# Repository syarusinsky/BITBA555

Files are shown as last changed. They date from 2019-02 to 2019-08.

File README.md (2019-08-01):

# BITBA555
BITBA555 is an open source/open hardware hybrid analog/digital monophonic synthesizer with a digital oscillator section and analog filter, amplifier, and envelope generator sections. It also features a fully 3D printable enclosure with snap-fit so that no additional hardware is necessary.

The ethos of BITBA555 is to be as close to 100% open source and DIY as possible. All code versions, hardware schematic versions, simulation files, board files, and even 3D printed enclosure designs will be shared on this page. In order to make digesting this information more accessible, a YouTube tutorial series about the design process has been created as well.

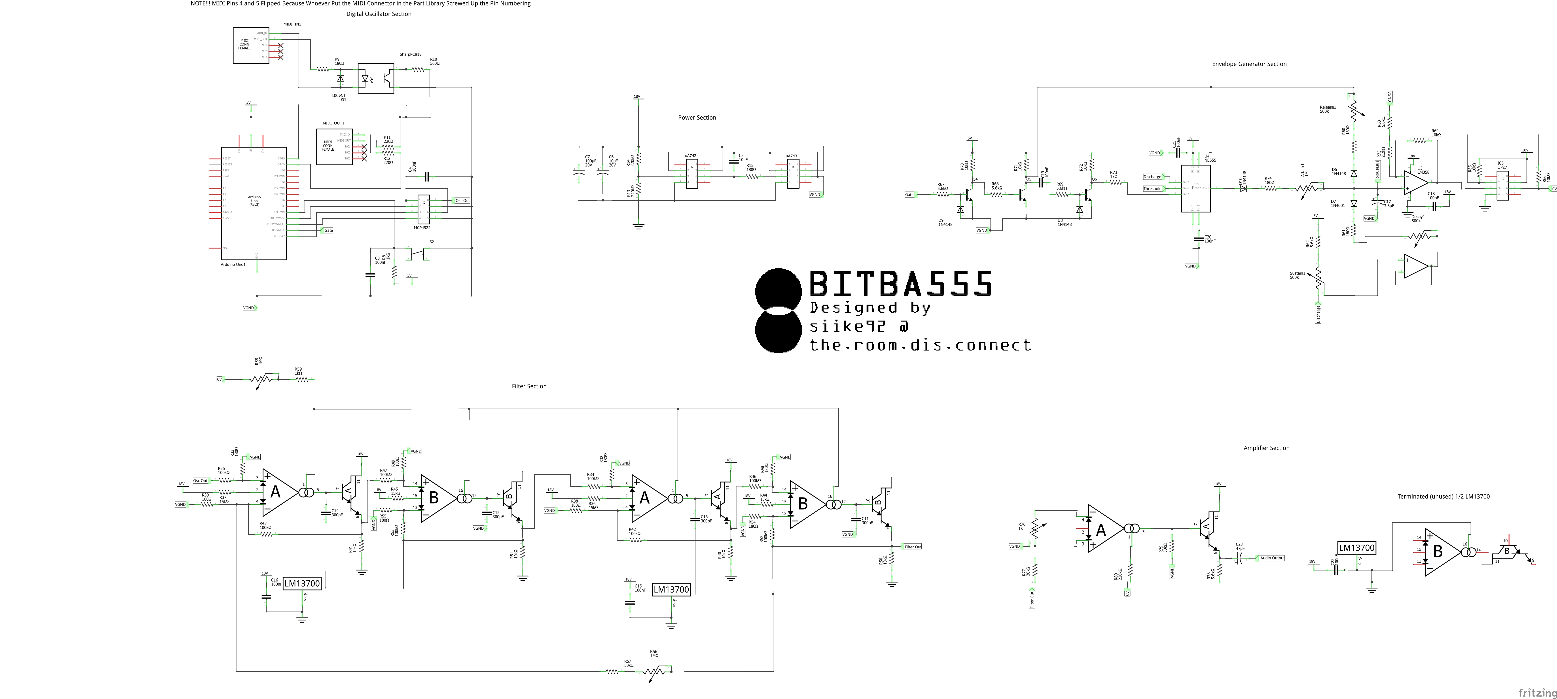
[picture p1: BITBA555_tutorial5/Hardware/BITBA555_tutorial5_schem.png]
Schematic

DIY PCB2
3D Printed Enclosure

### Episode 000 - Introduction
https://www.youtube.com/watch?v=HbYsLG5ng4g

### Episode 001 - BITBA555 Peripheral Setup
https://www.youtube.com/watch?v=4lw_u7kjT1c

### Episode 002 - BITBA555 Digital Oscillator Finished
https://www.youtube.com/watch?v=C3nDFvrVApo

### Episode 003 - BITBA555 Analog Filter and Power Supply
https://www.youtube.com/watch?v=efnBC_zZduA

### Episode 004 - BITA555 Analog Envelope Generator and Amplifier
https://www.youtube.com/watch?v=gevD3INR1kk

### Episode 005 - BITBA555 Board Layout and Fabrication
https://www.youtube.com/watch?v=fseVMmLj8Y8

### Episode 007 - BITBA555 Enclosure Design
https://www.youtube.com/watch?v=aarRZwyo6pU

## BITBA555 Features
* Digital oscillator section with sine, triangle, square, and sawtooth wave output
  * Dynamic programming techniques utilized to allow for underpowered ATmega328p to oscillate efficiently
* MIDI input and output with input support for MIDI note on and off messages
* Velocity sensitivity on wave amplitude for MIDI note on messages
* 4-pole analog OTA-based low-pass filter with cutoff and resonance control
  * Filter self oscillates at max resonance
* Analog OTA-based amplifier section with gain control
* Analog ADSR envelope generator 
* Fully 3D printed enclosure

To hear BITBA555 in a song: https://soundcloud.com/theroomdisconnect/bitbac1d/s-NRedz

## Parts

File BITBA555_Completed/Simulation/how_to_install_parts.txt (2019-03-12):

The "lib" folder contains parts that are used in the simulation files. To install these parts, go to your "Documents/LTSpiceXVII" directory (or
wherever else LTSpice stores your projects), then copy the files into their associated directories under the "Documents/LTSpiceXVII/lib" directory.
The lib directory in this folder is laid out exactly like the one in your project directory so this should be straightforward.

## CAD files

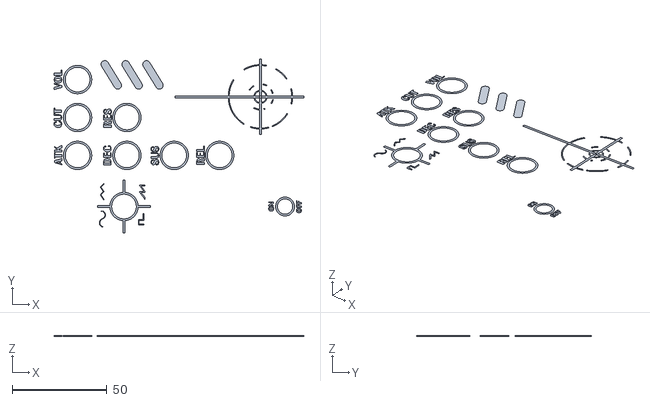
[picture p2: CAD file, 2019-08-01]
BITBA555_Completed/Hardware/BITBA555_enclosure/EnclosureTopSilkscreen.stl
131.9 x 91.9 x 0.2

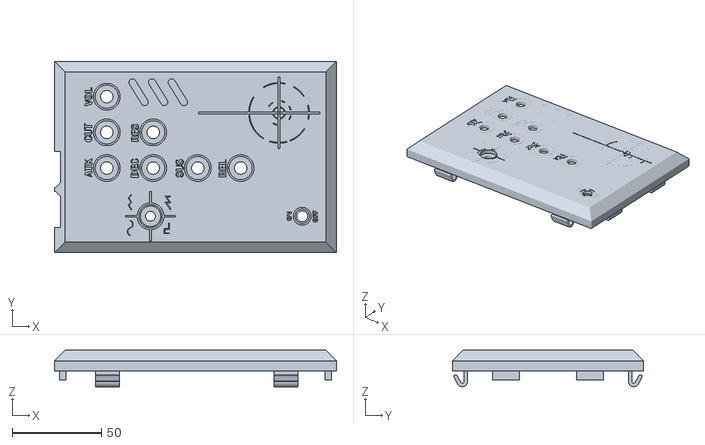
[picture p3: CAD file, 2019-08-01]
BITBA555_Completed/Hardware/BITBA555_enclosure/EnclosureTop.stl
158.0 x 107.2 x 20.5

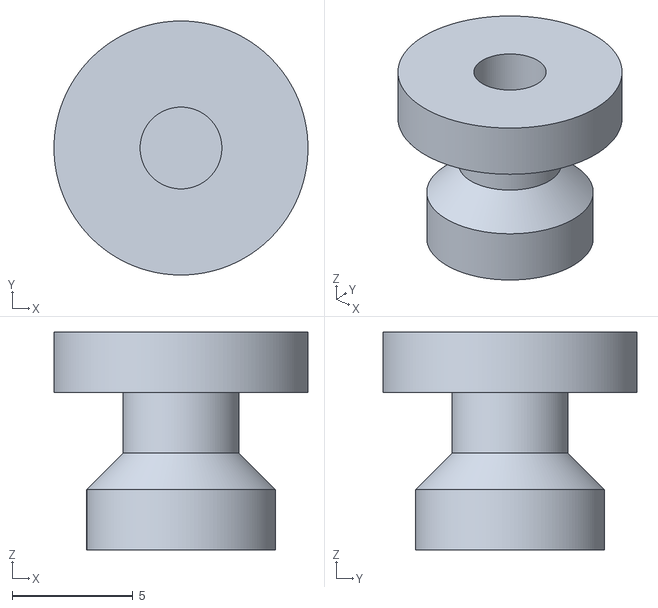
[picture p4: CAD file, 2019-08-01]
BITBA555_Completed/Hardware/BITBA555_enclosure/EnclosureSwitchBottom.stl
10.5 x 10.5 x 9.00

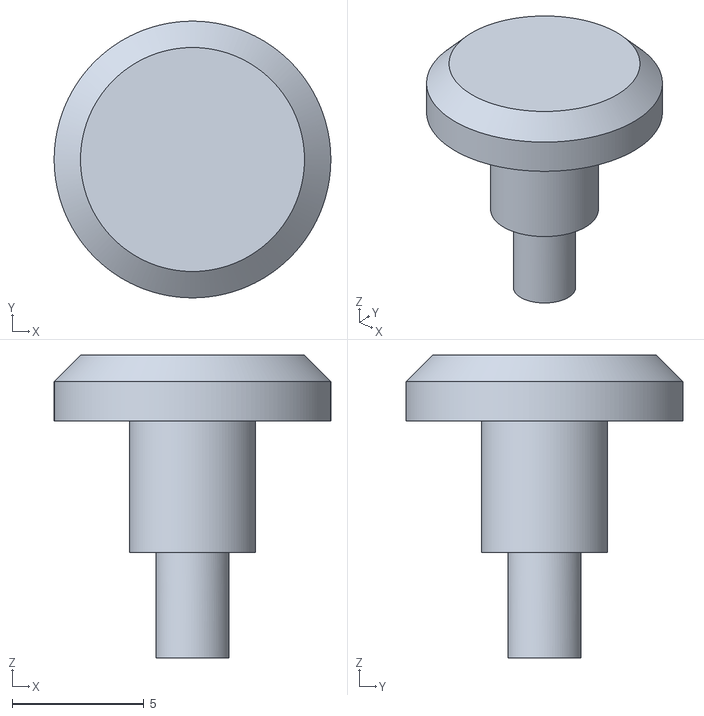
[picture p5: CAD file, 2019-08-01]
BITBA555_Completed/Hardware/BITBA555_enclosure/EnclosureSwitchTop.stl
10.5 x 10.5 x 11.5

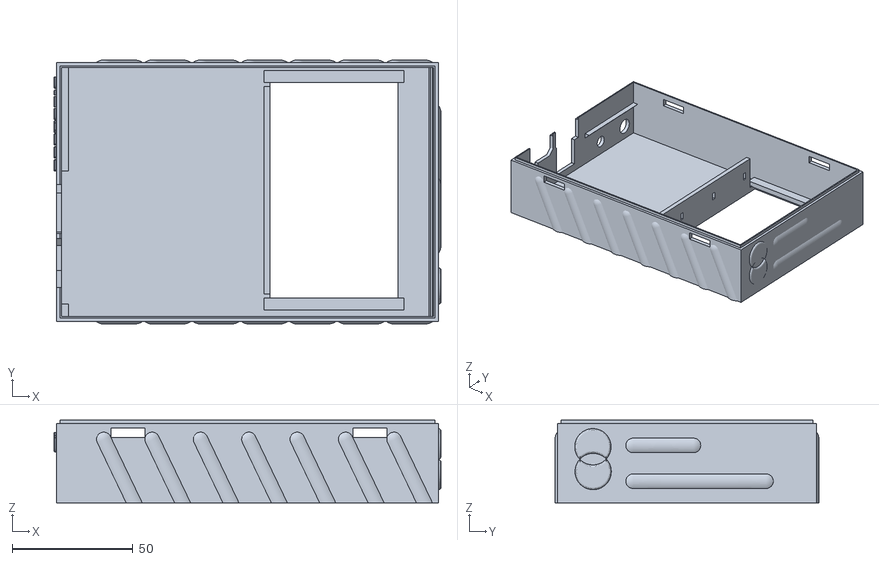
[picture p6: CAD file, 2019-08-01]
BITBA555_Completed/Hardware/BITBA555_enclosure/EnclosureBottom.stl
160.0 x 109.2 x 34.3

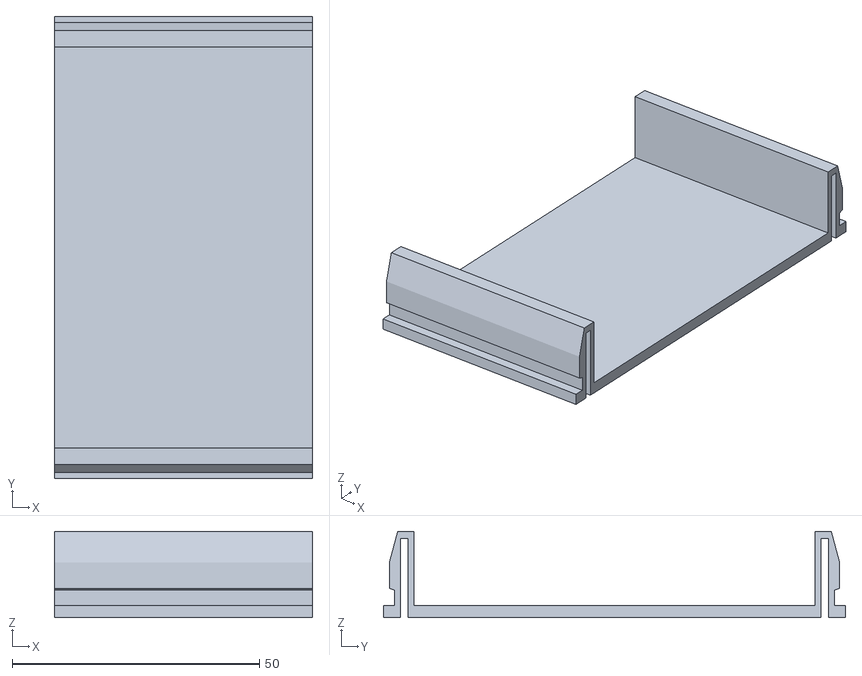
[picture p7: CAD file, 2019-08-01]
BITBA555_Completed/Hardware/BITBA555_enclosure/EnclosureBatteryCover.stl
52.2 x 93.5 x 17.5

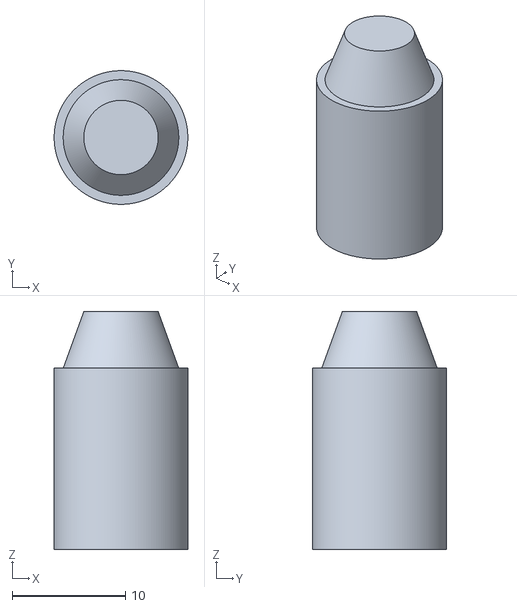
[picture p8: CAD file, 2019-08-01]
BITBA555_Completed/Hardware/BITBA555_enclosure/EnclosureKnob.stl
11.8 x 11.8 x 21.0

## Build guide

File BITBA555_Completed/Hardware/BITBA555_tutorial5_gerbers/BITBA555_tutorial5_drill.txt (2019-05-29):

; NON-PLATED HOLES START AT T1
; THROUGH (PLATED) HOLES START AT T100
M48
INCH
T100C0.042000
T101C0.035000
T102C0.015748
T103C0.040278
T104C0.088356
T105C0.041361
T106C0.055118
T107C0.041333
T108C0.030000
%
T100
X017567Y034042
X008906Y033873
X008118Y015145
X018355Y026562
X008906Y030893
X006544Y032861
X003394Y026562
X003394Y029542
X006544Y035841
X008118Y012165
X018355Y029542
X014587Y034042
T101
X032921Y008239
X026473Y014357
X018355Y024593
X023473Y016357
X028591Y021900
X027016Y033255
X033315Y027318
X034827Y003333
X039221Y036979
X015992Y012389
X033646Y013570
X004512Y024200
X028921Y002152
X010236Y035830
X013173Y031680
X035071Y036648
X036071Y036648
X033315Y029318
X010087Y024562
X015142Y035617
X013780Y018688
X023079Y027743
X024984Y006089
X025835Y028467
X033315Y028318
X036071Y002152
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

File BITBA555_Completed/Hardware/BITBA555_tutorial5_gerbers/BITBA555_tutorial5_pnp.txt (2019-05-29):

*Pick And Place List
*Company=
*Author=
*eMail=
*
*Project=BITBA555_tutorial5
*Date=13:13:57
*CreatedBy=Fritzing 0.9.3b.04.19.5c895d327c44a3114e5fcc9d8260daf0cbb52806
*
*
*Coordinates in mm, always center of component
*Origin 0/0=Lower left corner of PCB
*Rotation in degree (0-360, math. pos.)
*
*No;Value;Package;X;Y;Rotation;Side;Name
1;;;100.457;-24.3715;0;Bottom;Copper Fill201
2;;;25.5905;-68.6056;0;Bottom;Copper Fill215
3;;;51.7144;-61.1126;0;Bottom;Copper Fill122
4;100nF;100 mil [THT, multilayer];29.8916;-94.4684;0;Bottom;C21
5;180;THT;80.6216;-42.3883;-90;Bottom;R38
6;;;10.16;-88.6462;0;Bottom;Copper Fill91
7;;;37.6216;-52.4684;0;Bottom;Via16
8;;;46.5328;-78.9942;0;Bottom;Copper Fill100
9;;;7.8994;-60.3252;0;Bottom;Copper Fill120
10;;;19.4818;-44.1708;0;Bottom;Copper Fill28
11;15k;THT;72.6217;-50.5485;-90;Bottom;R36
12;;;23.5712;-65.9894;0;Bottom;Copper Fill17
13;;;40.5892;-82.4867;0;Bottom;Copper Fill48
14;;;96.5581;-11.4556;0;Bottom;Copper Fill200
15;10k;THT;93.5417;-74.4685;180;Bottom;R66
16;;;77.6217;-58.4683;0;Bottom;Via33
17;;;28.6216;-52.4684;0;Bottom;Via20
18;;;98.5393;-33.4266;0;Bottom;Copper Fill60
19;;;53.5813;-16.1292;0;Bottom;Copper Fill62
20;;;48.5394;-32.182;0;Bottom;Copper Fill163
21;;;67.1068;-31.4708;0;Bottom;Copper Fill162
22;10k;THT;100.542;-3.46843;0;Bottom;R51
23;;;12.6746;-82.4867;0;Bottom;Copper Fill46
24;;;47.6215;-3.46824;0;Bottom;Via38
25;;;99.7966;-92.3038;0;Bottom;Copper Fill5
26;;;34.6216;-52.4684;0;Bottom;Via22
27;;;97.5614;-10.973;0;Bottom;Copper Fill185
28;100k;THT;77.6216;-45.3883;-90;Bottom;R34
29;;;52.6217;-10.4684;0;Bottom;Via9
30;;;18.1356;-93.015;0;Bottom;Copper Fill86
31;;;19.6218;-52.4684;0;Bottom;Via21
32;;;24.8412;-91.0719;0;Bottom;Copper Fill72
33;;;87.4268;-11.1254;0;Bottom;Copper Fill178
34;;;45.1866;-60.884;0;Bottom;Copper Fill124
35;;;22.6218;-52.4684;0;Bottom;Via17
36;;;76.3524;-48.0824;0;Bottom;Copper Fill26
37;180;THT;96.6216;-15.3884;-90;Bottom;R55
38;;;22.8854;-38.9384;0;Bottom;Copper Fill156
39;;;69.5833;-15.4434;0;Bottom;Copper Fill204
40;;;67.6216;-10.4684;0;Bottom;Via11
41;;;74.9554;-6.5788;0;Bottom;Copper Fill184
42;;;42.5577;-6.02;0;Bottom;Copper Fill40
43;;;18.1102;-81.0262;0;Bottom;Copper Fill98
44;;;36.0426;-18.5676;0;Bottom;Copper Fill171
45;;;28.6512;-91.1608;0;Bottom;Copper Fill89
46;180;THT;11.5418;-79.4683;180;Bottom;R60
47;220;THT;24.7015;-13.4684;0;Bottom;R12
48;10k;THT;16.7016;-67.4682;0;Bottom;R70
49;;;42.5577;-17.577;0;Bottom;Copper Fill43
50;;;81.9404;-52.4258;0;Bottom;Copper Fill24
51;;;74.0918;-43.3326;0;Bottom;Copper Fill148
52;;;88.0364;-51.4098;0;Bottom;Copper Fill23
53;;TO92 [THT];5.71048;-64.7377;-90;Bottom;Q4
54;;;39.5605;-83.5408;0;Bottom;Copper Fill193
55;;;21.971;-49.0222;0;Bottom;Copper Fill139
56;;;110.82;-18.212;0;Bottom;Copper Fill173
57;;;87.7824;-1.9306;0;Bottom;Copper Fill39
58;;;109.738;-26.6574;-90;Bottom;TXT7
59;10k;THT;104.622;-45.3883;-90;Bottom;R40
60;;;41.2496;-91.872;0;Bottom;Copper Fill3
61;;;101.622;-55.4683;0;Bottom;Via35
62;;;71.501;-19.5455;0;Bottom;Copper Fill61
63;220k;THT;55.6218;-31.3884;90;Bottom;R14
64;;;53.5813;-16.1292;0;Bottom;Copper Fill206
65;180;THT;20.5415;-76.4683;180;Bottom;R74
66;;;43.6217;-52.4684;0;Bottom;Via24
67;5.6k;THT;65.7016;-96.4683;0;Bottom;R78
68;;;71.6026;-21.9839;0;Bottom;Copper Fill73
69;;;93.3196;-24.9176;0;Bottom;Copper Fill169
70;180;THT;98.6217;-39.5483;90;Bottom;R48
71;;;86.7918;-76.632;0;Bottom;Copper Fill102
72;;;16.7132;-28.3466;0;Bottom;Copper Fill31
73;;;25.6218;-52.4684;0;Bottom;Via19
74;1k;THT;35.6215;-18.5484;-90;Bottom;R8
75;;;8.5725;-73.8888;0;Bottom;Copper Fill212
76;;;97.7392;-37.9478;0;Bottom;Copper Fill157
77;;;72.1106;-60.0204;0;Bottom;Copper Fill118
78;;;77.8256;-87.4778;0;Bottom;Copper Fill4
79;30k;THT;99.6216;-82.5485;-90;Bottom;R79
80;;;57.6072;-71.4758;0;Bottom;Copper Fill12
81;180;THT;43.5415;-90.4685;180;Bottom;R61
82;;;44.6218;-3.46824;0;Bottom;Via39
83;;;80.9752;-76.9368;0;Bottom;Copper Fill101
84;;;40.8178;-50.0128;0;Bottom;Copper Fill33
85;;;34.9377;-38.8114;0;Bottom;Copper Fill67
86;180;THT;101.622;-29.3883;-90;Bottom;R54
87;;;55.2958;-39.9798;0;Bottom;Copper Fill152
88;180;THT;96.7018;-5.46826;180;Bottom;R49
89;;;94.1832;-21.9966;0;Bottom;Copper Fill172
90;;;64.6215;-52.4684;0;Bottom;Via28
91;;;64.6215;-10.4684;0;Bottom;Via13
92;;;36.5252;-49.9112;0;Bottom;Copper Fill137
93;;;52.4764;-15.0243;0;Bottom;Copper Fill63
94;;;86.4616;-52.9084;0;Bottom;Copper Fill133
95;;;47.6216;-10.4684;0;Bottom;Via8
96;;;81.7372;-17.1198;0;Bottom;Copper Fill175
97;220k;THT;51.6215;-31.5484;-90;Bottom;R13
98;;;53.1622;-91.6434;0;Bottom;Copper Fill85
99;;;57.5437;-96.6218;0;Bottom;Copper Fill219
100;;;44.5897;-2.6418;0;Bottom;Copper Fill188
101;;;73.66;-53.264;0;Bottom;Copper Fill25
102;;300 mil [THT];8.62161;-71.2528;-90;Bottom;D9
103;;;9.7536;-75.0699;0;Bottom;Copper Fill70
104;;;41.1226;-61.1888;0;Bottom;Copper Fill121
105;1k;THT;94.6218;-61.3883;90;Bottom;R59
106;;;102.108;-90.9576;0;Bottom;Copper Fill88
107;;;87.4268;-23.3428;0;Bottom;Copper Fill166
108;;;57.3532;-34.9506;0;Bottom;Copper Fill159
109;;;23.6216;-71.4683;0;Bottom;Via36
110;;;103.607;-11.9763;0;Bottom;Copper Fill54
111;;;73.1012;-48.8444;0;Bottom;Copper Fill136
112;;[THT];50.3715;-17.2183;0;Bottom;S2
113;;;24.8412;-91.0719;0;Bottom;Copper Fill214
114;;;57.5437;-98.3998;0;Bottom;Copper Fill218
115;;;43.688;-3.5435;0;Bottom;Copper Fill42
116;;;71.6788;-37.5287;0;Bottom;Copper Fill220
117;;;97.8281;-28.2196;0;Bottom;Copper Fill202
118;;;43.688;-3.5435;0;Bottom;Copper Fill189
119;;;58.6215;-52.4684;0;Bottom;Via30
120;;;109.622;-14.4684;0;Bottom;Via40
121;;;49.9872;-67.3864;0;Bottom;Copper Fill16
122;;;25.019;-69.1136;0;Bottom;Copper Fill111
123;;;49.9364;-88.0366;0;Bottom;Copper Fill93
124;;;50.4698;-63.6018;0;Bottom;Copper Fill19
125;;;41.6216;-10.4684;0;Bottom;Via7
126;;;91.5797;-6.6296;0;Bottom;Copper Fill58
127;;TO92 [THT];25.7104;-64.7377;-90;Bottom;Q5
128;;;50.165;-41.4276;0;Bottom;Copper Fill150
129;;;94.0054;-48.946;0;Bottom;Copper Fill141
130;;;26.0858;-94.0564;0;Bottom;Copper Fill1
131;;DIP (Dual Inline) [THT];87.4316;-19.6584;0;Bottom;IC4
132;;;29.5529;-40.8942;0;Bottom;Copper Fill210
133;;;13.081;-25.8828;0;Bottom;Copper Fill167
134;;;45.2628;-50.0128;0;Bottom;Copper Fill80
135;;DIP (Dual Inline) [THT];63.4317;-23.1983;0;Bottom;uA743
136;;;8.1534;-10.4142;0;Bottom;Copper Fill181
137;;;81.788;-45.7202;0;Bottom;Copper Fill27
138;;;70.612;-75.9208;0;Bottom;Copper Fill106
139;100k;THT;96.6216;-44.3884;-90;Bottom;R46
140;;;28.5877;-95.5804;0;Bottom;Copper Fill196
141;;;52.6217;-52.4684;0;Bottom;Via27
142;;;31.0896;-79.045;0;Bottom;Copper Fill99
143;10k;THT;54.7017;-65.4684;0;Bottom;R72
144;;;47.752;-75.0699;0;Bottom;Copper Fill78
145;;;58.6218;-10.4684;0;Bottom;Via10
146;;;88.2396;-57.2518;0;Bottom;Copper Fill126
147;;;83.5406;-82.3216;0;Bottom;Copper Fill96
148;;;98.8568;-29.2483;0;Bottom;Copper Fill57
149;;;61.6218;-10.4684;0;Bottom;Via14
150;;;97.8281;-28.2196;0;Bottom;Copper Fill56
151;1k;THT;51.7017;-62.4684;0;Bottom;R73
152;;;91.5797;-4.4198;0;Bottom;Copper Fill203
153;;;26.1112;-42.469;0;Bottom;Copper Fill146
154;;TO92 [THT];43.7106;-64.7377;-90;Bottom;Q6
155;;THT;42.152;-100.293;-90;Bottom;Decay1
156;;;66.0908;-21.9839;0;Bottom;Copper Fill74
157;5.6k;THT;38.5417;-80.4682;180;Bottom;R62
158;;;13.6906;-54.0514;0;Bottom;Copper Fill127
159;;;16.6624;-64.44;0;Bottom;Copper Fill112
160;15k;THT;94.6218;-21.5484;-90;Bottom;R45
161;;;33.782;-93.65;0;Bottom;Copper Fill2
162;;;102.641;-24.3715;0;Bottom;Copper Fill53
163;;;91.5416;-74.3714;0;Bottom;Copper Fill109
164;;;38.608;-88.3668;0;Bottom;Copper Fill8
165;100k;THT;93.5417;-8.46828;0;Bottom;R47
166;;;42.5577;-6.02;0;Bottom;Copper Fill186
167;;;36.6268;-42.2912;0;Bottom;Copper Fill155
168;;;90.4748;-5.5247;0;Bottom;Copper Fill59
169;;;20.193;-41.707;0;Bottom;Copper Fill151
170;3.3µF;100 mil [THT, electrolytic];11.6216;-83.7384;-90;Bottom;C17
171;220;THT;24.7015;-27.4683;0;Bottom;R11
172;;;39.5605;-83.5408;0;Bottom;Copper Fill47
173;;;109.622;-19.4683;0;Bottom;Via42
174;;;68.7197;-69.4184;0;Bottom;Copper Fill198
175;2.2k;THT;65.6217;-77.3884;90;Bottom;R75
176;;;33.8328;-39.9163;0;Bottom;Copper Fill211
177;;;42.8244;-83.0582;0;Bottom;Copper Fill97
178;;;46.6217;-52.4684;0;Bottom;Via25
179;5.6k;THT;16.7016;-64.4685;0;Bottom;R68
180;;;86.6902;-5.9438;0;Bottom;Copper Fill182
181;;;86.6648;-73.1268;0;Bottom;Copper Fill13
182;100nF;100 mil [THT, multilayer];58.8916;-75.4684;0;Bottom;C18
183;;;53.1368;-97.9172;0;Bottom;Copper Fill81
184;;;20.6756;-29.9722;0;Bottom;Copper Fill168
185;;;104.597;-75.5398;0;Bottom;Copper Fill11
186;;300 mil [THT];22.6215;-82.253;-90;Bottom;D10
187;;;100.457;-24.3715;0;Bottom;Copper Fill52
188;;;86.6648;-73.0252;0;Bottom;Copper Fill107
189;;;104.369;-52.883;0;Bottom;Copper Fill132
190;10k;THT;104.622;-32.3883;-90;Bottom;R50
191;;;15.5395;-6.29007;0;Bottom;IMG1
192;;THT;111.447;-63.4779;0;Bottom;R56
193;;;5.5753;-68.6056;0;Bottom;Copper Fill68
194;;300 mil [THT];46.6217;-71.2528;-90;Bottom;D8
195;;;91.6178;-60.0204;0;Bottom;Copper Fill125
196;;;85.979;-37.7954;0;Bottom;Copper Fill30
197;;;48.1584;-15.0243;0;Bottom;Copper Fill209
198;;;21.9964;-19.0248;0;Bottom;Copper Fill170
199;;;11.5697;-81.4072;0;Bottom;Copper Fill191
200;;;55.6218;-10.4684;0;Bottom;Via12
201;100k;THT;86.7018;-32.4685;180;Bottom;R42
202;;;74.9554;-55.169;0;Bottom;Copper Fill130
203;560;THT;63.5418;-47.4683;180;Bottom;R10
204;;DIP (Dual Inline) [THT];63.4317;-37.7384;0;Bottom;uA742
205;;;25.654;-8.9664;0;Bottom;Copper Fill179
206;;;44.6216;-10.4684;0;Bottom;Via5
207;;;95.9866;-90.7544;0;Bottom;Copper Fill90
208;;;92.2528;-29.5404;0;Bottom;Copper Fill164
209;;;37.348;-2.72593;0;Bottom;TXT7
210;300pF;100 mil [THT, multilayer];96.6216;-29.1935;180;Bottom;C11
211;;;55.6218;-52.4684;0;Bottom;Via31
212;;THT;52.152;-100.293;-90;Bottom;Sustain1
213;;;109.764;-7.37142;-90;Bottom;TXT7
214;;;46.5709;-73.8888;0;Bottom;Copper Fill77
215;;;7.8486;-72.7204;0;Bottom;Copper Fill105
216;;;57.6218;-97.4683;0;Bottom;Via37
217;;THT;111.446;-82.938;0;Bottom;R76
218;;;47.9044;-64.186;0;Bottom;Copper Fill115
219;;;78.9432;-55.3976;0;Bottom;Copper Fill22
220;;;23.7744;-61.9508;0;Bottom;Copper Fill117
221;;;97.8281;-30.3024;0;Bottom;Copper Fill55
222;;;32.6218;-10.4684;0;Bottom;Via4
223;;;86.2076;-88.1382;0;Bottom;Copper Fill6
224;;;7.366;-75.0699;0;Bottom;Copper Fill69
225;180;THT;74.7017;-16.4684;0;Bottom;R39
226;;;105.918;-45.39;0;Bottom;Copper Fill140
227;;;13.6144;-39.2178;0;Bottom;Copper Fill154
228;;;52.4764;-15.0243;0;Bottom;Copper Fill207
229;100µF;200 mil [THT, electrolytic];43.1617;-31.4683;0;Bottom;C7
230;;DIP8 [THT];29.8117;-87.1984;0;Bottom;U4
231;47µF;100 mil [THT, electrolytic];99.6216;-95.1983;90;Bottom;C23
232;;300 mil [THT];20.6217;-34.6839;90;Bottom;D2
233;300pF;100 mil [THT, multilayer];77.6216;-36.1938;-90;Bottom;C13
234;;;61.0108;-69.647;0;Bottom;Copper Fill15
235;;DIP (Dual Inline) [THT];38.8118;-43.6583;90;Bottom;MCP4922
236;;din_5_female_support;9.37165;-40.5093;90;Bottom;MIDI_IN1
237;;;33.6804;-64.2876;0;Bottom;Copper Fill113
238;;DIP (Dual Inline) [THT];87.8118;-89.2784;-90;Bottom;IC6
239;;;25.9461;-92.1768;0;Bottom;Copper Fill213
240;100nF;100 mil [THT, multilayer];38.3517;-82.4684;180;Bottom;C20
241;;;49.6217;-52.4684;0;Bottom;Via26
242;100nF;100 mil [THT, multilayer];105.622;-20.743;90;Bottom;C15
243;;;40.0177;-38.8114;0;Bottom;Copper Fill75
244;;;45.7962;-5.0802;0;Bottom;Copper Fill183
245;;;84.1183;-96.3164;0;Bottom;TXT6
246;50k;THT;74.5417;-2.46852;0;Bottom;R57
247;5.6k;THT;16.5416;-61.4685;180;Bottom;R67
248;;DIP8 [THT];56.4317;-83.7384;180;Bottom;U3
249;;;16.2814;-32.817;0;Bottom;Copper Fill161
250;10pF;100 mil [THT, multilayer];70.6216;-23.1983;90;Bottom;C5
251;;;48.133;-93.8786;0;Bottom;Copper Fill83
252;;;17.6276;-81.0262;0;Bottom;Copper Fill10
253;;;25.9461;-92.1768;0;Bottom;Copper Fill71
254;;;36.2049;-31.1584;0;Bottom;Arduino Uno1
255;;;81.6102;-8.9664;0;Bottom;Copper Fill180
256;10k;THT;93.5417;-71.4685;180;Bottom;R65
257;;THT;18.1522;-100.293;-90;Bottom;Attack1
258;;;45.974;-34.2648;0;Bottom;Copper Fill158
259;100nF;100 mil [THT, multilayer];74.6215;-89.1985;90;Bottom;C22
260;;;41.3258;-88.8494;0;Bottom;Copper Fill92
261;;;33.147;-29.4896;0;Bottom;Copper Fill160
262;;;55.0544;-2.76629;0;Bottom;TXT7
263;;;40.6217;-52.4684;0;Bottom;Via23
264;;;54.6608;-15.0243;0;Bottom;Copper Fill208
265;10µF;100 mil [THT, electrolytic];43.8918;-23.4684;0;Bottom;C6
266;;;16.6218;-52.4684;0;Bottom;Via15
267;;;27.5336;-94.5263;0;Bottom;Copper Fill49
268;300pF;100 mil [THT, multilayer];79.6217;-12.1936;-90;Bottom;C14
269;;;102.616;-44.6534;0;Bottom;Copper Fill145
270;;;23.5712;-66.3196;0;Bottom;Copper Fill114
271;;;69.8246;-70.4979;0;Bottom;Copper Fill199
272;100k;THT;100.622;-42.3883;-90;Bottom;R52
273;;;81.4578;-15.2148;0;Bottom;Copper Fill176
274;180;THT;90.5417;-34.4683;0;Bottom;R32
275;;;72.6216;-37.4684;0;Bottom;Via34
276;;;69.6468;-64.0336;0;Bottom;Copper Fill18
277;;;74.4474;-2.718;0;Bottom;Copper Fill38
278;;;37.5666;-72.4156;0;Bottom;Copper Fill104
279;;;63.6016;-47.7776;0;Bottom;Copper Fill138
280;;;90.297;-50.0128;0;Bottom;Copper Fill36
281;;;46.5709;-76.2764;0;Bottom;Copper Fill76
282;30k;THT;102.622;-89.5485;-90;Bottom;R77
283;;;74.6217;-62.4685;0;Bottom;Via41
284;;THT;8.15217;-100.293;-90;Bottom;Release1
285;;;94.6658;-41.199;0;Bottom;Copper Fill153
286;180;THT;68.5416;-15.4685;180;Bottom;R15
287;;;60.6552;-24.5239;0;Bottom;Copper Fill79
288;;;45.3644;-75.0699;0;Bottom;Copper Fill216
289;;;39.5605;-81.458;0;Bottom;Copper Fill194
290;;;26.6217;-10.4684;0;Bottom;Via1
291;;;41.529;-16.5483;0;Bottom;Copper Fill190
292;100nF;100 mil [THT, multilayer];41.8917;-13.4684;180;Bottom;C4
293;;;31.6216;-52.4684;0;Bottom;Via18
294;;;17.145;-80.2388;0;Bottom;Copper Fill94
295;;;79.8576;-67.5642;0;Bottom;Copper Fill14
296;;;98.4504;-77.5083;0;Bottom;Copper Fill65
297;;;81.7372;-17.1198;0;Bottom;Copper Fill34
298;;;89.7128;-21.006;0;Bottom;Copper Fill32
299;15k;THT;94.6218;-48.3883;-90;Bottom;R44
300;100nF;100 mil [THT, multilayer];28.6216;-70.1985;-90;Bottom;C19
301;100k;THT;72.7016;-29.4684;0;Bottom;R35
302;;;29.6218;-10.4684;0;Bottom;Via2
303;;;100.66;-77.5083;0;Bottom;Copper Fill66
304;;;94.2086;-45.5932;0;Bottom;Copper Fill147
305;;;96.9264;-47.1934;0;Bottom;Copper Fill144
306;;;79.9592;-58.979;0;Bottom;Copper Fill123
307;;;68.4784;-16.5483;0;Bottom;Copper Fill205
308;;;100.609;-42.2404;0;Bottom;Copper Fill116
309;;;75.5142;-51.4352;0;Bottom;Copper Fill134
310;180;THT;75.5416;-19.4685;180;Bottom;R33
311;;;103.861;-50.0128;0;Bottom;Copper Fill177
312;;;38.6215;-10.4684;0;Bottom;Via6
313;;DIP (Dual Inline) [THT];80.8115;-73.1985;0;Bottom;IC5
314;;;79.6544;-44.9328;0;Bottom;Copper Fill143
315;100k;THT;78.7016;-8.46828;0;Bottom;R43
316;;300 mil [THT];16.6218;-87.2529;-90;Bottom;D6
317;;;43.2308;-92.253;0;Bottom;Copper Fill87
318;;;41.0972;-62.9922;0;Bottom;Copper Fill21
319;;;68.7197;-69.4184;0;Bottom;Copper Fill50
320;;;67.6216;-52.4684;0;Bottom;Via29
321;;300 mil [THT];40.837;-86.4683;180;Bottom;D7
322;10k;THT;78.5416;-5.46826;0;Bottom;R41
323;;;27.5336;-94.5263;0;Bottom;Copper Fill197
324;;;41.529;-16.5483;0;Bottom;Copper Fill44
325;100nF;100 mil [THT, multilayer];43.8918;-16.4684;0;Bottom;C3
326;;;82.1944;-70.4598;0;Bottom;Copper Fill108
327;;;13.9446;-46.7108;0;Bottom;Copper Fill142
328;;;10.4648;-82.4867;0;Bottom;Copper Fill45
329;;;58.5978;-86.157;0;Bottom;Copper Fill84
330;;;23.7236;-62.4842;0;Bottom;Copper Fill20
331;;;61.6215;-52.4684;0;Bottom;Via32
332;220k;THT;83.5417;-82.4684;180;Bottom;R80
333;;;102.21;-23.5206;0;Bottom;Copper Fill174
334;;;80.5688;-51.9432;0;Bottom;Copper Fill135
335;15k;THT;73.6216;-35.3883;90;Bottom;R37
336;;;88.9254;-76.632;0;Bottom;Copper Fill9
337;;;46.1518;-5.1056;0;Bottom;Copper Fill37
338;;;58.4708;-39.0527;0;Bottom;Copper Fill217
339;;;81.4832;-55.3976;0;Bottom;Copper Fill129
340;;;40.5892;-82.4867;0;Bottom;Copper Fill195
341;;din_5_female_support;9.37165;-18.5092;90;Bottom;MIDI_OUT1
342;;;24.1046;-81.204;0;Bottom;Copper Fill95
343;100nF;100 mil [THT, multilayer];83.347;-58.4685;0;Bottom;C16
344;100k;THT;100.622;-15.3884;-90;Bottom;R53
345;;;77.6478;-15.2148;0;Bottom;Copper Fill35
346;180;THT;24.7015;-47.4683;0;Bottom;R9
347;;;76.6064;-61.2142;0;Bottom;Copper Fill119
348;;DIP (Dual Inline) [THT];87.8118;-46.5784;0;Bottom;IC3
349;;;12.6746;-82.4867;0;Bottom;Copper Fill192
350;10k;THT;68.6218;-79.3885;90;Bottom;R64
351;5.6k;THT;33.7016;-65.4684;0;Bottom;R69
352;;;35.6218;-10.4684;0;Bottom;Via3
353;;;71.0692;-43.485;0;Bottom;Copper Fill149
354;;;100.406;-54.1784;0;Bottom;Copper Fill131
355;;;38.6334;-93.6754;0;Bottom;Copper Fill82
356;;;97.0788;-88.189;0;Bottom;Copper Fill7
357;;;44.5897;-2.6418;0;Bottom;Copper Fill41
358;;;48.1584;-15.0243;0;Bottom;Copper Fill64
359;;;25.5905;-51.4352;0;Bottom;Copper Fill187
360;;THT;111.446;-72.938;0;Bottom;R58
361;300pF;100 mil [THT, multilayer];102.622;-13.1938;-90;Bottom;C12
362;;;74.9808;-76.8098;0;Bottom;Copper Fill103
363;;;96.1644;-55.423;0;Bottom;Copper Fill29
364;10k;THT;33.7016;-62.4684;0;Bottom;R71
365;;;101.536;-25.4764;0;Bottom;Copper Fill51
366;;;45.5676;-55.1944;0;Bottom;Copper Fill128
367;;;94.234;-67.9706;0;Bottom;Copper Fill110
368;;;40.132;-25.6542;0;Bottom;Copper Fill165
369;;THT;25.8115;-43.2839;0;Bottom;SharpPC818
370;5.6k;THT;63.7015;-70.4683;0;Bottom;R63

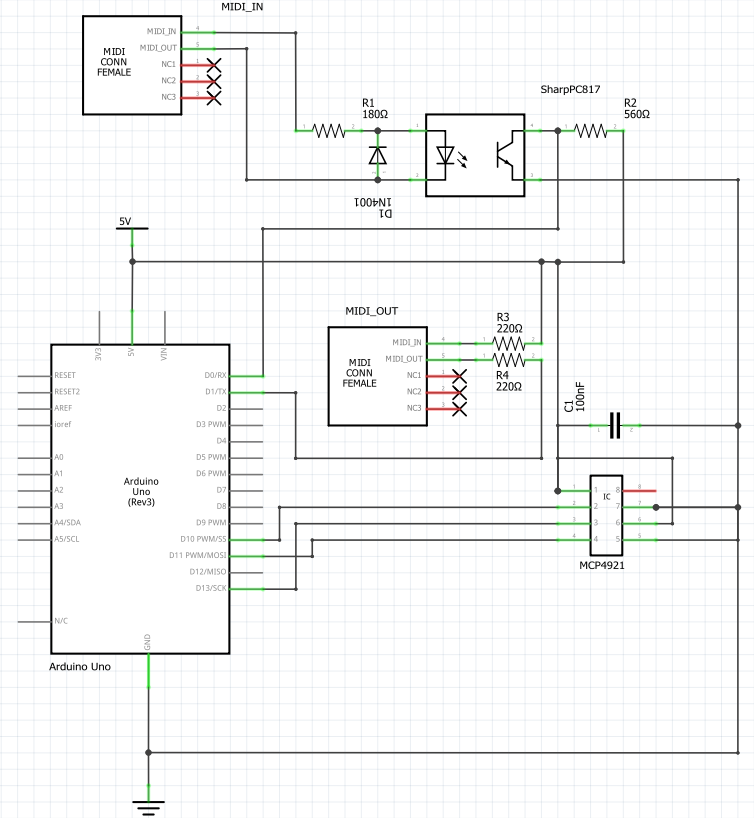
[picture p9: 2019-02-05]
BITBA555_tutorial1/Hardware/BITBA555_tutorial1_schematic.png

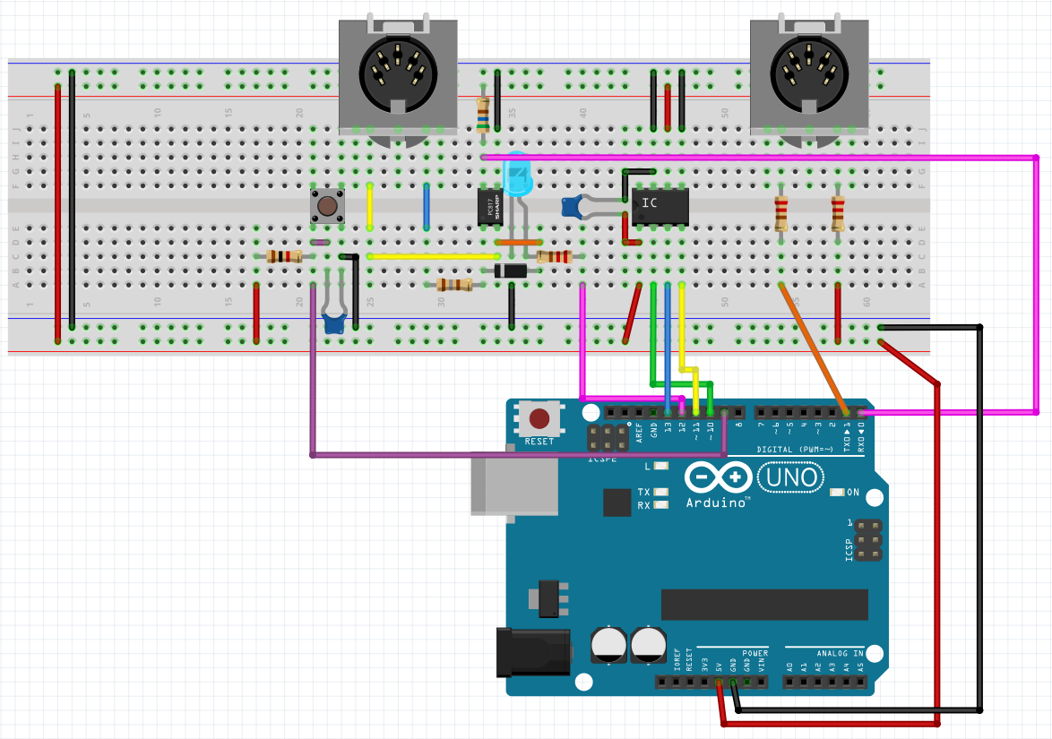
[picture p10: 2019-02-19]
BITBA555_tutorial4/Hardware/BITBA555_tutorial2_breadboard_layout.png

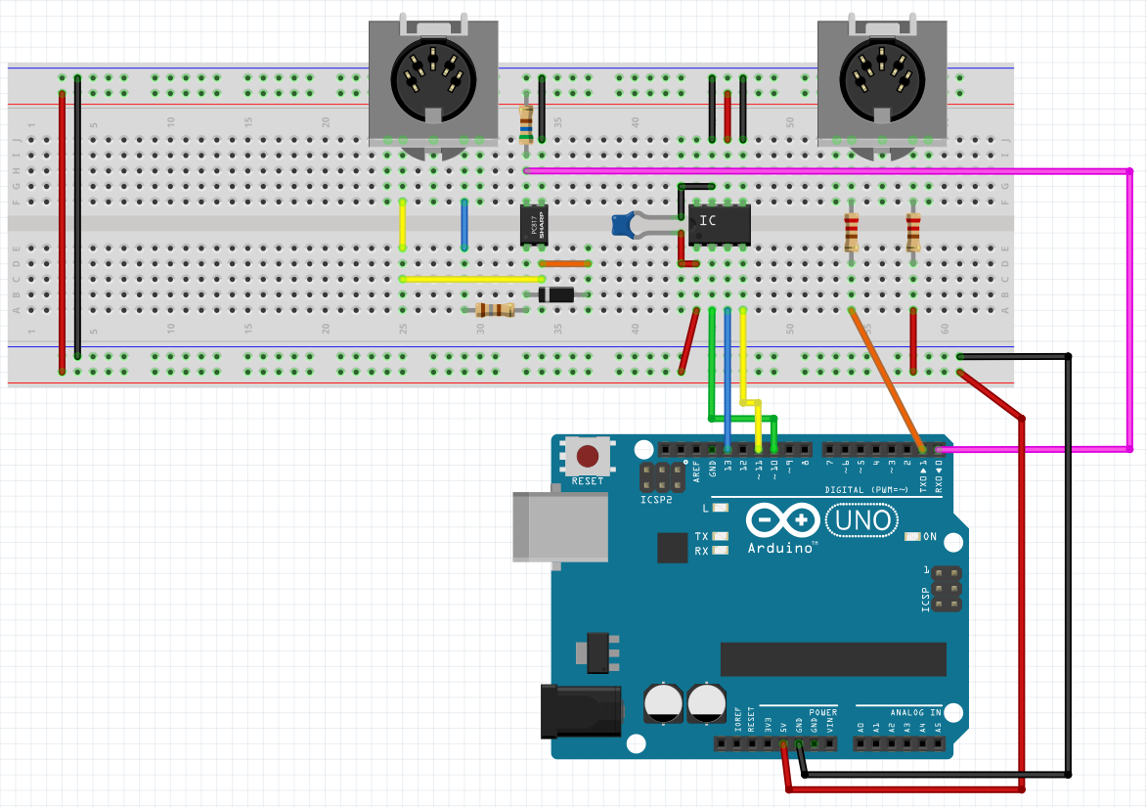
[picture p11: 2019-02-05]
BITBA555_tutorial1/Hardware/BITBA555_tutorial1_breadboard_layout.png

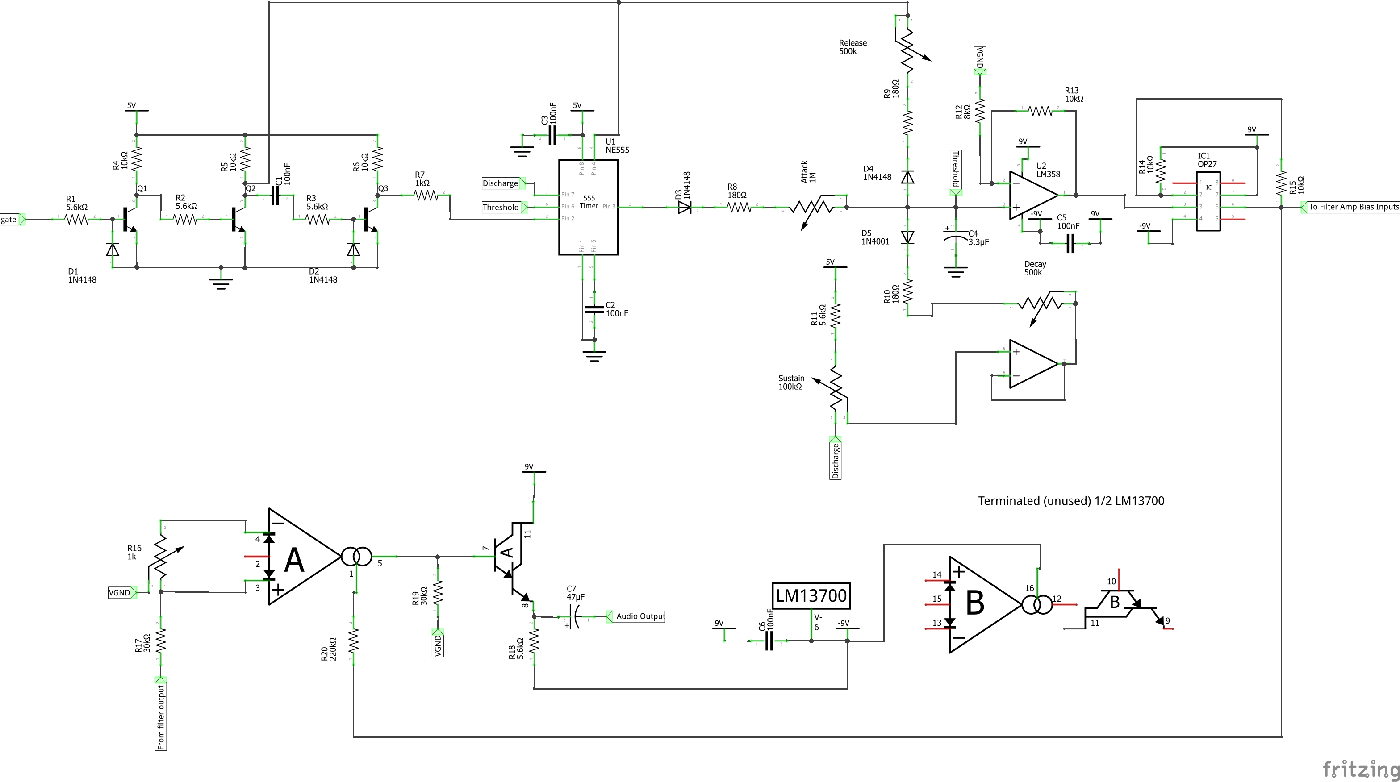
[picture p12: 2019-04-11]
BITBA555_tutorial4/Hardware/BITBA555_tutorial4_schematic.png

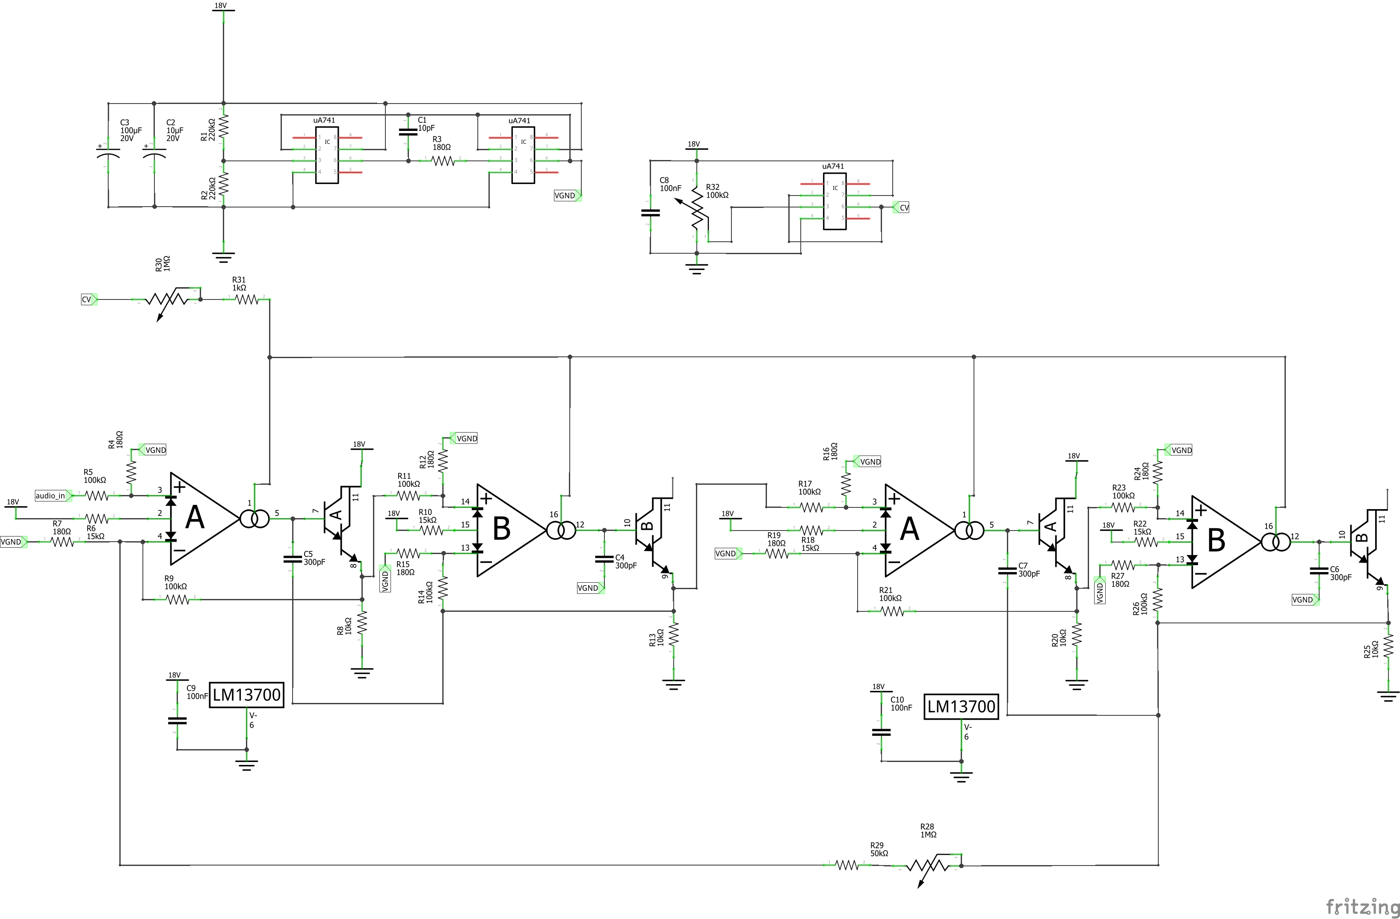
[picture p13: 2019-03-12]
BITBA555_tutorial4/Hardware/BITBA555_tutorial3_schematic.png

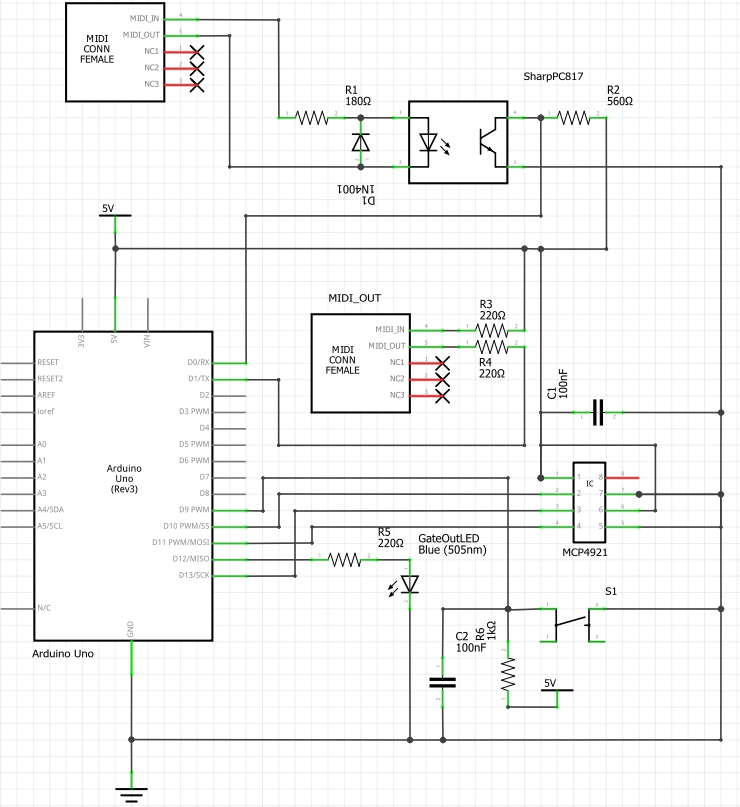
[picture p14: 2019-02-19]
BITBA555_tutorial4/Hardware/BITBA555_tutorial2_schematic.png

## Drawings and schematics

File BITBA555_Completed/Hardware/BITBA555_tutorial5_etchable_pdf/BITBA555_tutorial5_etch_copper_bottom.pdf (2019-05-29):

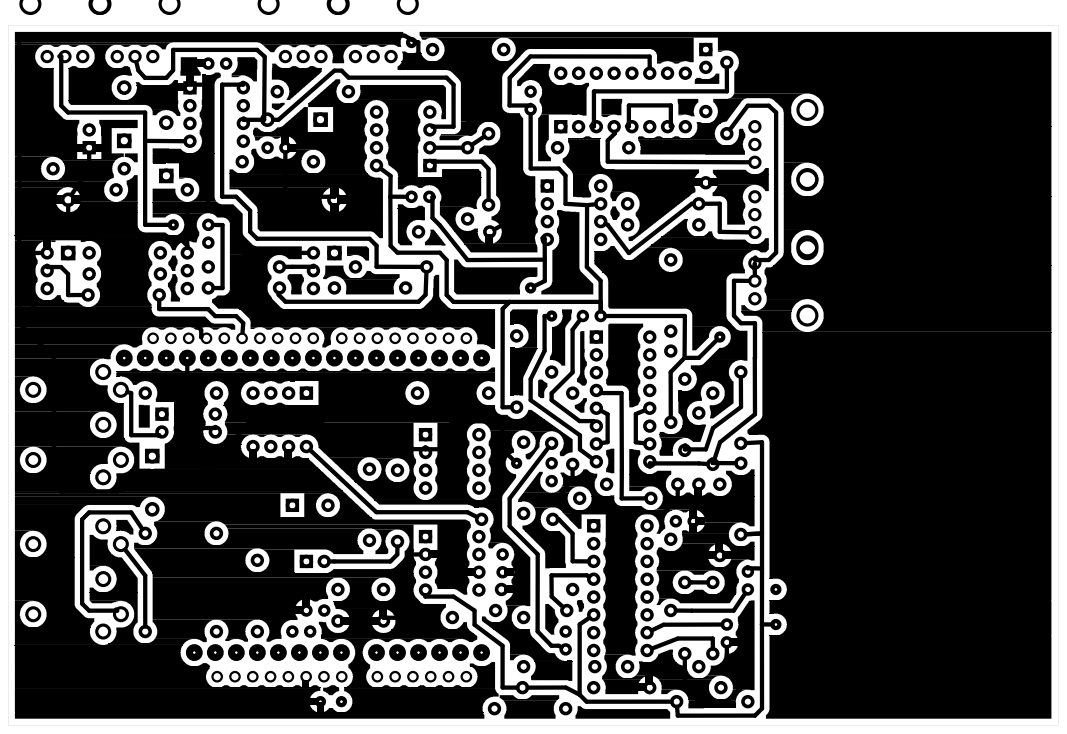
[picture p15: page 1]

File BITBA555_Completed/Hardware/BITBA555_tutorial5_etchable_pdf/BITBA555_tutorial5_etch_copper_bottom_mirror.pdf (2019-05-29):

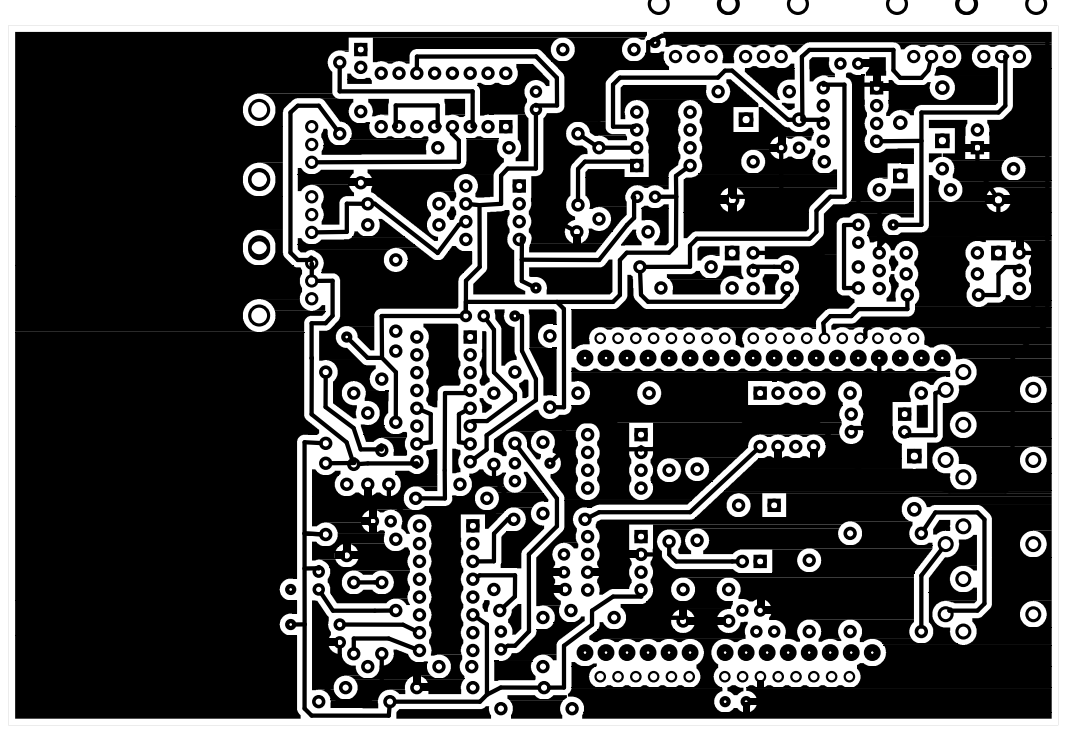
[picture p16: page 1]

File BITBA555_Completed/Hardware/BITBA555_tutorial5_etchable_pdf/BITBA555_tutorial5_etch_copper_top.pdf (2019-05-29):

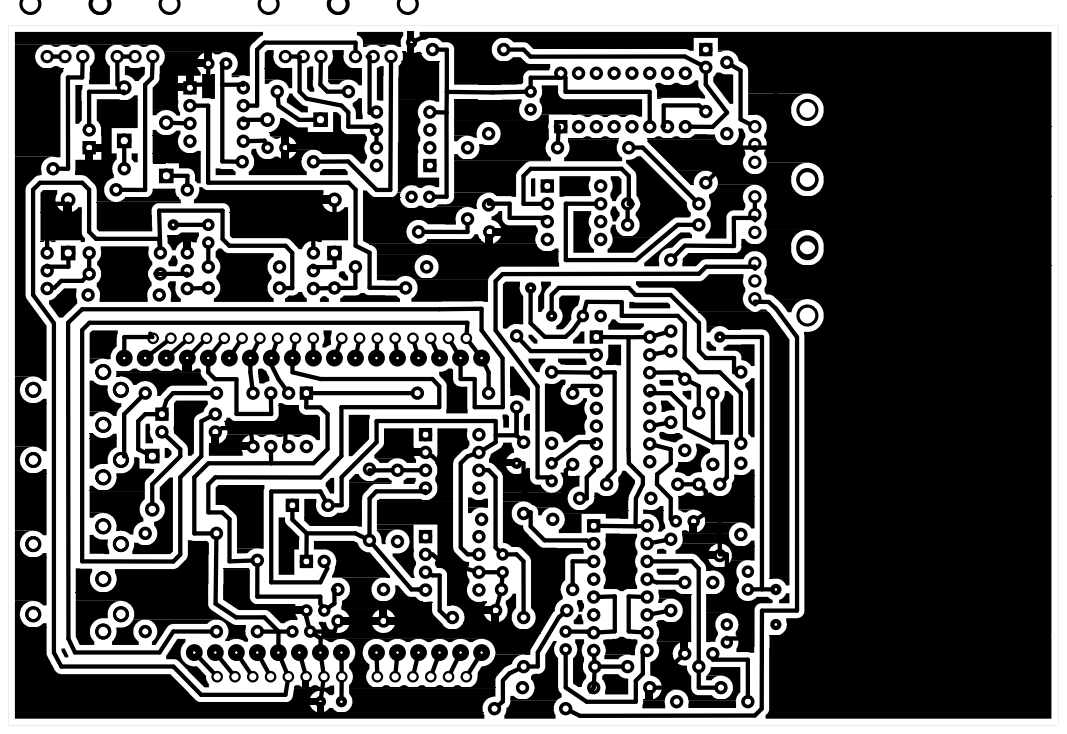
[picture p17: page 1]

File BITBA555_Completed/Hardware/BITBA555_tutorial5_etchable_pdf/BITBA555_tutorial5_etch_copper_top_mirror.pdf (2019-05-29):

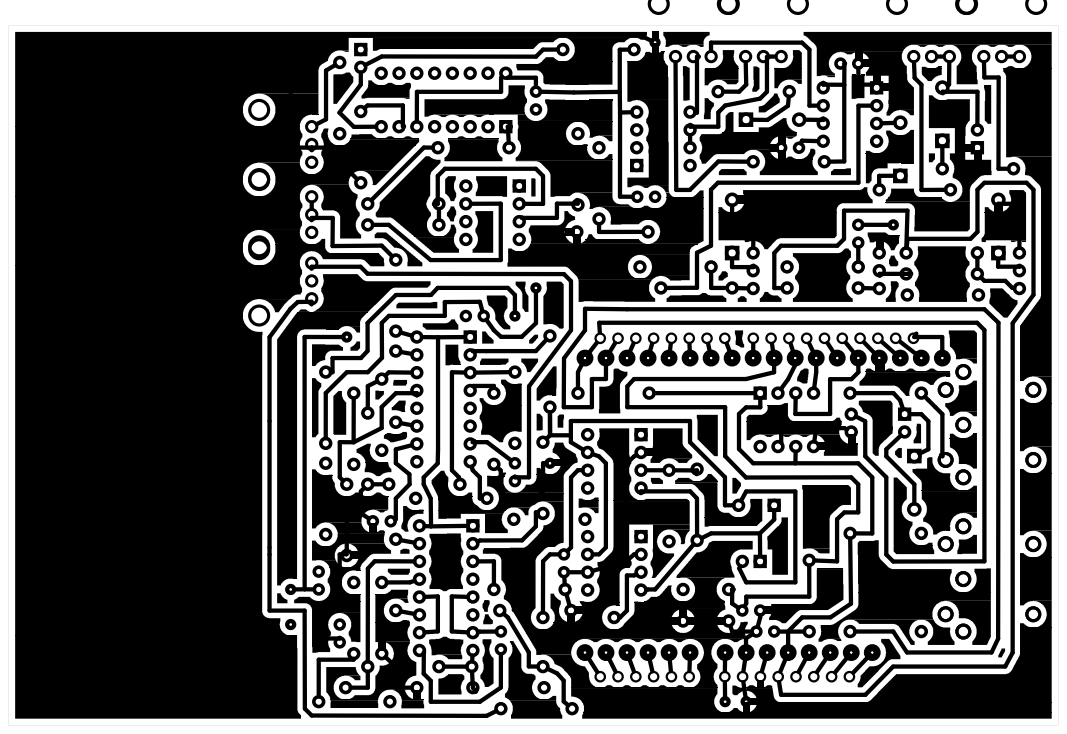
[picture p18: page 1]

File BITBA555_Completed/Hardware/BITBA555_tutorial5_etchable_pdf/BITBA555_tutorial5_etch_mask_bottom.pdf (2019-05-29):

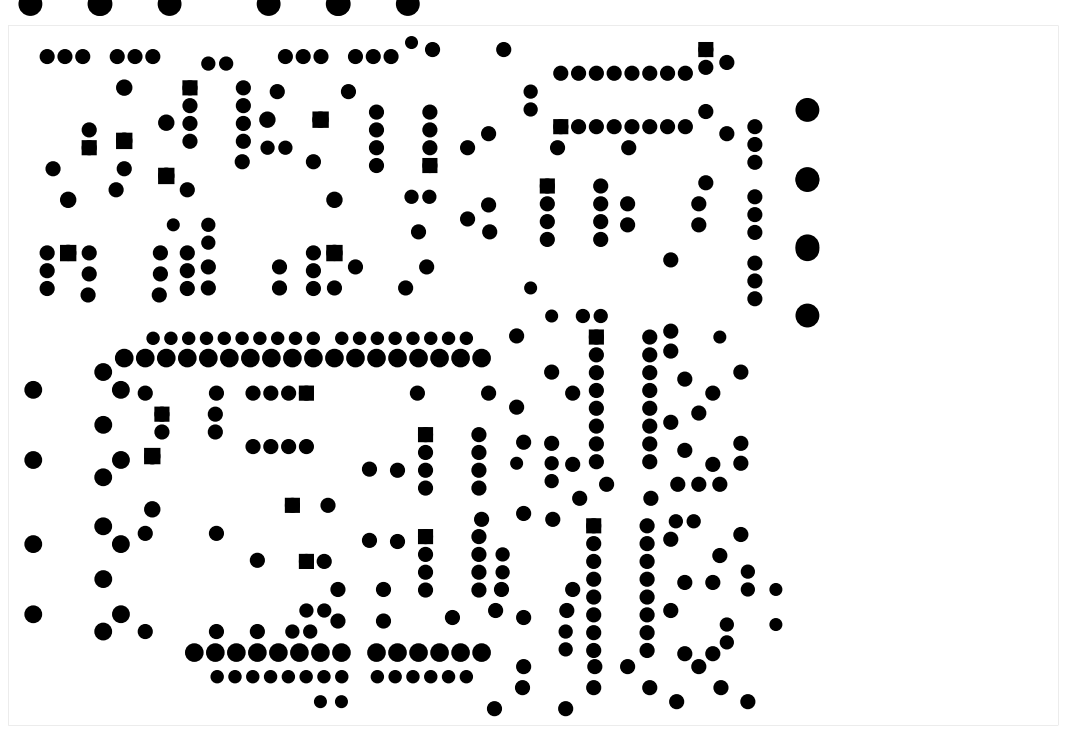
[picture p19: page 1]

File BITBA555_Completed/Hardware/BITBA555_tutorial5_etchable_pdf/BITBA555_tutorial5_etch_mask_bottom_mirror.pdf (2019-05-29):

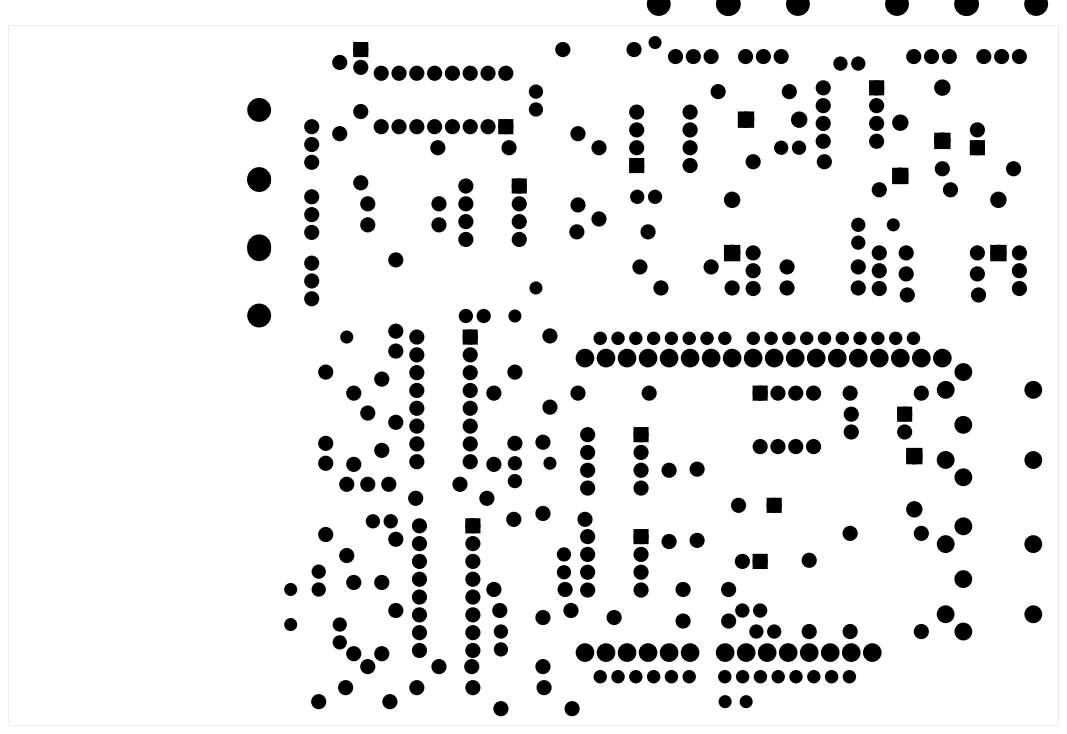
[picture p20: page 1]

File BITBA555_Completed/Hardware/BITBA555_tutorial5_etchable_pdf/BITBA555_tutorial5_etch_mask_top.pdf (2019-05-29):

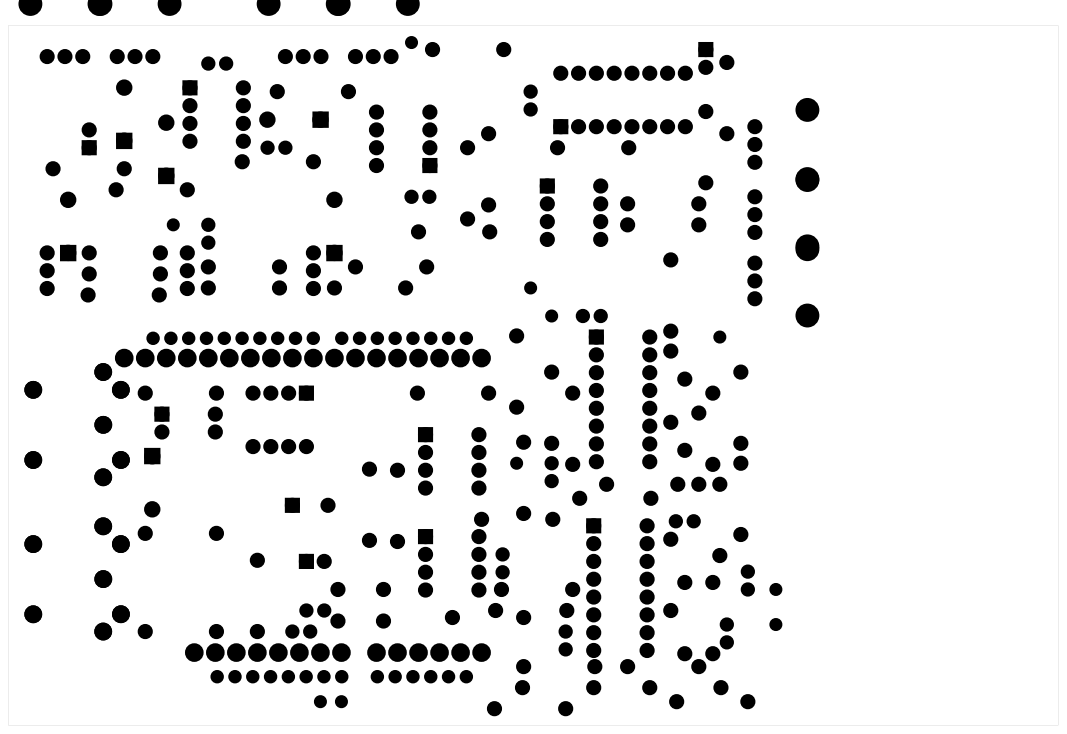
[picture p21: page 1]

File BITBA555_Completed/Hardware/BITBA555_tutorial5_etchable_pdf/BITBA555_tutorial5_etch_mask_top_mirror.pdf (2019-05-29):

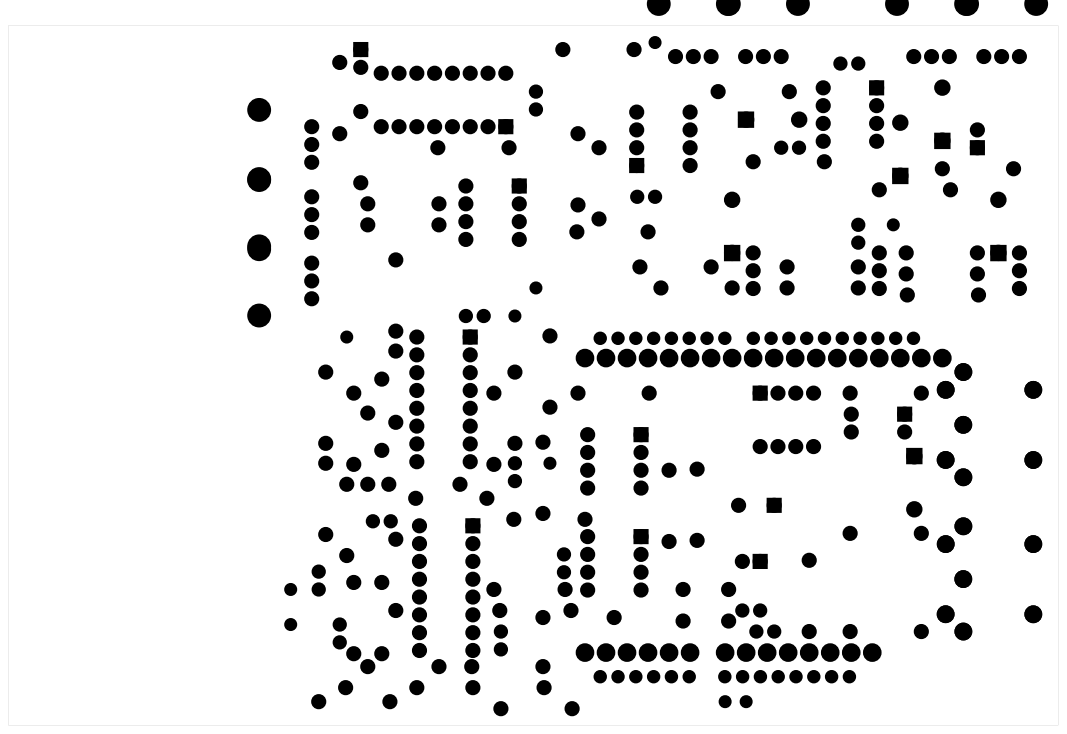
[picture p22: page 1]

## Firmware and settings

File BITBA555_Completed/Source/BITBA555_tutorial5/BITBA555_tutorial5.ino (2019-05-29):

#include "PeripheralSetup.h"
#include "SampleGeneration.h"
#include "MIDI.h"

#define INCREMENT_TABLE_SIZE 50   // an "increment table" is used to increment through the table at a given frequency without requiring floating point numbers (the larger the size, the more accurate the frequency)

#define GATE_OUT_PIN PINB4  // pinb4 will be used to control gate output and associated LED
#define WAVE_SELECTION_PIN PINB1  // pinb1 will be used as a button input to change waveforms

typedef struct voice  // this struct represents a synthesizer voice
{
  volatile uint16_t tablePos = 0;  // tablePos determines where in the waveform table the voice is currently
  uint8_t midiNote = 0; // midiNote records the current midi note value
  uint8_t ampVal = 0; // ampVal determines the amplitude value to apply to the note (should be 0 to 16)
  uint8_t incrTable[INCREMENT_TABLE_SIZE];  // the increment table values are used to increment through the table at a given frequency without requiring floating point numbers
  volatile uint8_t incrTablePos = 0;  // a value used to increment through the incrTable
  uint8_t previousNotes[10];  // these are the previous midiNote values in case of a key being released while other keys are still pressed, the Voice will play a previous note value until all keys are released
  uint8_t numNotesPressed = 0;  // the number of previous notes still being held
  uint8_t incrTableNeedsProc = 0; // 1 if the incrTable needs to be reprocessed, 0 if it doesn't
} Voice;

Voice osc; // the voice that will act as our digital oscillator

// Use this for tutorial before implementing MIDI notes
// volatile uint16_t timerWaveIncr = 0;

void processMidiEvent (const MidiEvent* const midiEvent); // takes in a MidiEvent and uses its data to correctly update the Voice data structure
void processIncrTable();  // processes the incrTable values for the Voice

uint8_t currentWaveIsSelected = 0;  // a boolean value used in the main loop to assure that while the button is being pressed, the synth isn't quickly flipping through waveforms
uint8_t currentWaveLocation = 0;  // this value is used to determine which wave in the waveBuffer is currently in use (0 for sine, 1 for triangle, 2 for square, 3 for sawtooth)

void setup () 
{
  cli();  // disable interrupts

  DDRB |= (1 << GATE_OUT_PIN);  // setup gate output/LED pin
  PORTB &= ~(1 << GATE_OUT_PIN); // set gate output/LED pin low
  DDRB &= ~(1 << WAVE_SELECTION_PIN); // set up wave selection pin as input

  // setup peripherals
  Timer1Initialize();
  USART_Init();
  SPIDAC_MasterInit();

  // setup waveform buffers
  generateSine();
  generateTriangle();
  generateSquare();
  generateSawtooth();
  
  sei();  // enable interrupts
}

void loop () 
{
  while (midiReadIndex != midiWriteIndex) // while there are MidiEvents in the MIDI event buffer, process them
  {
    processMidiEvent(&midiEventBuffer[midiReadIndex]);
    midiReadIndex = (midiReadIndex + 1) % MIDI_EVENT_BUFFER_SIZE;
  }

  if (osc.incrTableNeedsProc) // if incrTable needs processing (this is done after the processMidiEvent loop so that if a bunch of notes are pressed at once, we don't waste processing on all of them since their incrTables won't be used)
  {
    processIncrTable();
  }
  
  if (PINB & (1 << WAVE_SELECTION_PIN) && !currentWaveIsSelected) // if the wave selection button is pressed and it hasn't remained high since last loop...
  {
    currentWaveLocation = (currentWaveLocation + 1) % 4;
    switch (currentWaveLocation)
    {
      case 0  :
        currentWave = sineWave;
        break;
      case 1  :
        currentWave = triangleWave;
        break;
      case 2  :
        currentWave = squareWave;
        break;
      case 3  :
        currentWave = sawtoothWave;
        break;
      default :
        currentWave = sineWave;
    }
    currentWaveIsSelected = 1;
  } else if ( !(PINB & (1 << WAVE_SELECTION_PIN)) && currentWaveIsSelected )  // if the wave selection button isn't pressed and a wave was just selected...
  {
    currentWaveIsSelected = 0;
  }
}

void processMidiEvent (const MidiEvent* const midiEvent)
{
  if ( (midiEvent->statusByte >> 4) == MIDI_NOTE_OFF || midiEvent->dataByte[1] == 0) // if note off message,...
  {
    osc.numNotesPressed -= 1; // a key has been released so the number of notes pressed simultaneously is -= 1
    
    if (osc.numNotesPressed == 0) // if no more notes are being held
    {
      PORTB &= ~(1 << GATE_OUT_PIN);  // set gate output to low 
    } else
    {
      osc.midiNote = osc.previousNotes[osc.numNotesPressed];  // set the current note to the previous note in the buffer
      osc.incrTableNeedsProc = 1; // since we're using a previous note, the incrTable needs to be reprocessed
    }
  }
  else  // if note on message,... 
  {
    osc.midiNote = midiEvent->dataByte[0]; // set the midi note value of the Voice struct to the current midi note being processed
    osc.ampVal = round (midiEvent->dataByte[1] / 8);  // this will give us a amplitude of 0-16, which will keep us within clipping range (ex. 255 * 16 = 4080 < 4095)
    osc.numNotesPressed += 1; // this note is pressed so the number of notes pressed simultaneously is += 1
    osc.previousNotes[osc.numNotesPressed] = midiEvent->dataByte[0];  // put this value into the previous note buffer to be processed if a key after this is released but this key is still pressed
    osc.incrTableNeedsProc = 1; // we are processing a new note, so the incrTable needs to be reprocessed

    PORTB |= (1 << GATE_OUT_PIN); // set gate output to high to prepare outputting audio
  }
}

void processIncrTable()
{
  float runningIncr = 0.0;  // the running total for incrementing, to be rounded off and placed 
  float incr = 0.0; // the floating point value to increment by to achieve desired frequency
  
  switch (osc.midiNote) // matching the midi note value to the associated incr value
  {
    case MIDI_C0  :
      incr = MUSIC_C0;
      break;
    case MIDI_Db0  :
      incr = MUSIC_Db0;
      break;
    case MIDI_D0  :
      incr = MUSIC_D0;
      break;
    case MIDI_Eb0  :
      incr = MUSIC_Eb0;
      break;
    case MIDI_E0  :
      incr = MUSIC_E0;
      break;
    case MIDI_F0  :
      incr = MUSIC_F0;
      break;
    case MIDI_Gb0  :
      incr = MUSIC_Gb0;
      break;
    case MIDI_G0  :
      incr = MUSIC_G0;
      break;
    case MIDI_Ab0  :
      incr = MUSIC_Ab0;
      break;
    case MIDI_A0  :
      incr = MUSIC_A0;
      break;
    case MIDI_Bb0  :
      incr = MUSIC_Bb0;
      break;
    case MIDI_B0  :
      incr = MUSIC_B0;
      break;
    case MIDI_C1  :
      incr = MUSIC_C1;
      break;
    case MIDI_Db1  :
      incr = MUSIC_Db1;
      break;
    case MIDI_D1  :
      incr = MUSIC_D1;
      break;
    case MIDI_Eb1  :
      incr = MUSIC_Eb1;
      break;
    case MIDI_E1  :
      incr = MUSIC_E1;
      break;
    case MIDI_F1  :
      incr = MUSIC_F1;
      break;
    case MIDI_Gb1  :
      incr = MUSIC_Gb1;
      break;
    case MIDI_G1  :
      incr = MUSIC_G1;
      break;
    case MIDI_Ab1  :
      incr = MUSIC_Ab1;
      break;
    case MIDI_A1  :
      incr = MUSIC_A1;
      break;
    case MIDI_Bb1  :
      incr = MUSIC_Bb1;
      break;
    case MIDI_B1  :
      incr = MUSIC_B1;
      break;
    case MIDI_C2  :
      incr = MUSIC_C2;
      break;
    case MIDI_Db2  :
      incr = MUSIC_Db2;
      break;
    case MIDI_D2  :
      incr = MUSIC_D2;
      break;
    case MIDI_Eb2  :
      incr = MUSIC_Eb2;
      break;
    case MIDI_E2  :
      incr = MUSIC_E2;
      break;
    case MIDI_F2  :
      incr = MUSIC_F2;
      break;
    case MIDI_Gb2  :
      incr = MUSIC_Gb2;
      break;
    case MIDI_G2  :
      incr = MUSIC_G2;
      break;
    case MIDI_Ab2  :
      incr = MUSIC_Ab2;
      break;
    case MIDI_A2  :
      incr = MUSIC_A2;
      break;
    case MIDI_Bb2  :
      incr = MUSIC_Bb2;
      break;
    case MIDI_B2  :
      incr = MUSIC_B2;
      break;
    case MIDI_C3  :
      incr = MUSIC_C3;
      break;
    case MIDI_Db3  :
      incr = MUSIC_Db3;
      break;
    case MIDI_D3  :
      incr = MUSIC_D3;
      break;
    case MIDI_Eb3  :
      incr = MUSIC_Eb3;
      break;
    case MIDI_E3  :
      incr = MUSIC_E3;
      break;
    case MIDI_F3  :
      incr = MUSIC_F3;
      break;
    case MIDI_Gb3  :
      incr = MUSIC_Gb3;
      break;
    case MIDI_G3  :
      incr = MUSIC_G3;
      break;
    case MIDI_Ab3  :
      incr = MUSIC_Ab3;
      break;
    case MIDI_A3  :
      incr = MUSIC_A3;
      break;
    case MIDI_Bb3  :
      incr = MUSIC_Bb3;
      break;
    case MIDI_B3  :
      incr = MUSIC_B3;
      break;
    case MIDI_C4  :
      incr = MUSIC_C4;
      break;
    case MIDI_Db4  :
      incr = MUSIC_Db4;
      break;
    case MIDI_D4  :
      incr = MUSIC_D4;
      break;
    case MIDI_Eb4  :
      incr = MUSIC_Eb4;
      break;
    case MIDI_E4  :
      incr = MUSIC_E4;
      break;
    case MIDI_F4  :
      incr = MUSIC_F4;
      break;
    case MIDI_Gb4  :
      incr = MUSIC_Gb4;
      break;
    case MIDI_G4  :
      incr = MUSIC_G4;
      break;
    case MIDI_Ab4  :
      incr = MUSIC_Ab4;
      break;
    case MIDI_A4  :
      incr = MUSIC_A4;
      break;
    case MIDI_Bb4  :
      incr = MUSIC_Bb4;
      break;
    case MIDI_B4  :
      incr = MUSIC_B4;
      break;
    case MIDI_C5  :
      incr = MUSIC_C5;
      break;
    case MIDI_Db5  :
      incr = MUSIC_Db5;
      break;
    case MIDI_D5  :
      incr = MUSIC_D5;
      break;
    case MIDI_Eb5  :
      incr = MUSIC_Eb5;
      break;
    case MIDI_E5  :
      incr = MUSIC_E5;
      break;
    case MIDI_F5  :
      incr = MUSIC_F5;
      break;
    case MIDI_Gb5  :
      incr = MUSIC_Gb5;
      break;
    case MIDI_G5  :
      incr = MUSIC_G5;
      break;
    case MIDI_Ab5  :
      incr = MUSIC_Ab5;
      break;
    case MIDI_A5  :
      incr = MUSIC_A5;
      break;
    case MIDI_Bb5  :
      incr = MUSIC_Bb5;
      break;
    case MIDI_B5  :
      incr = MUSIC_B5;
      break;
    case MIDI_C6  :
      incr = MUSIC_C6;
      break;
    case MIDI_Db6  :
      incr = MUSIC_Db6;
      break;
    case MIDI_D6  :
      incr = MUSIC_D6;
      break;
    case MIDI_Eb6  :
      incr = MUSIC_Eb6;
      break;
    case MIDI_E6  :
      incr = MUSIC_E6;
      break;
    case MIDI_F6  :
      incr = MUSIC_F6;
      break;
    case MIDI_Gb6  :
      incr = MUSIC_Gb6;
      break;
    case MIDI_G6  :
      incr = MUSIC_G6;
      break;
    case MIDI_Ab6  :
      incr = MUSIC_Ab6;
      break;
    case MIDI_A6  :
      incr = MUSIC_A6;
      break;
    case MIDI_Bb6  :
      incr = MUSIC_Bb6;
      break;
    case MIDI_B6  :
      incr = MUSIC_B6;
      break;
    case MIDI_C7  :
      incr = MUSIC_C7;
      break;
    case MIDI_Db7  :
      incr = MUSIC_Db7;
      break;
    case MIDI_D7  :
      incr = MUSIC_D7;
      break;
    case MIDI_Eb7  :
      incr = MUSIC_Eb7;
      break;
    case MIDI_E7  :
      incr = MUSIC_E7;
      break;
    case MIDI_F7  :
      incr = MUSIC_F7;
      break;
    case MIDI_Gb7  :
      incr = MUSIC_Gb7;
      break;
    case MIDI_G7  :
      incr = MUSIC_G7;
      break;
    case MIDI_Ab7  :
      incr = MUSIC_Ab7;
      break;
    case MIDI_A7  :
      incr = MUSIC_A7;
      break;
    case MIDI_Bb7  :
      incr = MUSIC_Bb7;
      break;
    case MIDI_B7  :
      incr = MUSIC_B7;
      break;
    case MIDI_C8  :
      incr = MUSIC_C8;
      break;
    case MIDI_Db8  :
      incr = MUSIC_Db8;
      break;
    case MIDI_D8  :
      incr = MUSIC_D8;
      break;
    case MIDI_Eb8  :
      incr = MUSIC_Eb8;
      break;
    case MIDI_E8  :
      incr = MUSIC_E8;
      break;
    case MIDI_F8  :
      incr = MUSIC_F8;
      break;
    case MIDI_Gb8  :
      incr = MUSIC_Gb8;
      break;
    case MIDI_G8  :
      incr = MUSIC_G8;
      break;
    case MIDI_Ab8  :
      incr = MUSIC_Ab8;
      break;
    case MIDI_A8  :
      incr = MUSIC_A8;
      break;
    case MIDI_Bb8  :
      incr = MUSIC_Bb8;
      break;
    case MIDI_B8  :
      incr = MUSIC_B8;
      break;
    default :
      incr = MUSIC_C0;
  }

  for (int i = 0; i < INCREMENT_TABLE_SIZE; i++)
  {
    runningIncr += incr;  // keep track of the real floating point value of the incr
    osc.incrTable[i] = round (runningIncr) - round (runningIncr - incr);  // put the integer difference between the new rounded running total and the last 
  }

  osc.incrTableNeedsProc = 0;
}

ISR (TIMER1_COMPA_vect)
{
  SPIDAC_MasterTransmit ( currentWave[osc.tablePos] * osc.ampVal ); // output wave at current table position
  osc.tablePos = ( osc.tablePos + osc.incrTable[osc.incrTablePos] ) % INITIAL_WAVE_TABLE_SIZE; // update the table position using the incrTable and ensure it wraps around the wave table
  osc.incrTablePos = (osc.incrTablePos + 1) % INCREMENT_TABLE_SIZE; // update the increment table increment and make sure it wraps around the incr table
}

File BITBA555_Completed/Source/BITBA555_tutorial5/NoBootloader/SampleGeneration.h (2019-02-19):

#include <math.h>

#define INITIAL_WAVE_FREQUENCY 100 // one cycle of each waveform will be stored in the buffers will at this frequency in Hz
#define INITIAL_WAVE_TABLE_SIZE (SAMPLE_RATE / INITIAL_WAVE_FREQUENCY) // the waveforms stored in the buffers will need arrays of this size
#define M_PI 3.14159265359  // pi, though some of the end may be truncated

// correct floating point increment for each musical frequency (freq / sample rate gives us cycles per sample
// but then we have to multiply by the initial wave table size since 1 cycle is now (sample rate / initial wave frequency) samples
#define MUSIC_C0 INITIAL_WAVE_TABLE_SIZE * (16.35 / SAMPLE_RATE)
#define MUSIC_Db0 INITIAL_WAVE_TABLE_SIZE * (17.32 / SAMPLE_RATE)
#define MUSIC_D0 INITIAL_WAVE_TABLE_SIZE * (18.35 / SAMPLE_RATE)
#define MUSIC_Eb0 INITIAL_WAVE_TABLE_SIZE * (19.45 / SAMPLE_RATE)
#define MUSIC_E0 INITIAL_WAVE_TABLE_SIZE * (20.60 / SAMPLE_RATE)
#define MUSIC_F0 INITIAL_WAVE_TABLE_SIZE * (21.83 / SAMPLE_RATE)
#define MUSIC_Gb0 INITIAL_WAVE_TABLE_SIZE * (23.12 / SAMPLE_RATE)
#define MUSIC_G0 INITIAL_WAVE_TABLE_SIZE * (24.50 / SAMPLE_RATE)
#define MUSIC_Ab0 INITIAL_WAVE_TABLE_SIZE * (25.96 / SAMPLE_RATE)
#define MUSIC_A0 INITIAL_WAVE_TABLE_SIZE * (27.50 / SAMPLE_RATE)
#define MUSIC_Bb0 INITIAL_WAVE_TABLE_SIZE * (29.14 / SAMPLE_RATE)
#define MUSIC_B0 INITIAL_WAVE_TABLE_SIZE * (30.87 / SAMPLE_RATE)
#define MUSIC_C1 INITIAL_WAVE_TABLE_SIZE * (32.70 / SAMPLE_RATE)
#define MUSIC_Db1 INITIAL_WAVE_TABLE_SIZE * (34.65 / SAMPLE_RATE)
#define MUSIC_D1 INITIAL_WAVE_TABLE_SIZE * (36.71 / SAMPLE_RATE)
#define MUSIC_Eb1 INITIAL_WAVE_TABLE_SIZE * (38.89 / SAMPLE_RATE)
#define MUSIC_E1 INITIAL_WAVE_TABLE_SIZE * (41.20 / SAMPLE_RATE)
#define MUSIC_F1 INITIAL_WAVE_TABLE_SIZE * (43.65 / SAMPLE_RATE)
#define MUSIC_Gb1 INITIAL_WAVE_TABLE_SIZE * (46.25 / SAMPLE_RATE)
#define MUSIC_G1 INITIAL_WAVE_TABLE_SIZE * (49.00 / SAMPLE_RATE)
#define MUSIC_Ab1 INITIAL_WAVE_TABLE_SIZE * (51.91 / SAMPLE_RATE)
#define MUSIC_A1 INITIAL_WAVE_TABLE_SIZE * (55.00 / SAMPLE_RATE)
#define MUSIC_Bb1 INITIAL_WAVE_TABLE_SIZE * (58.27 / SAMPLE_RATE)
#define MUSIC_B1 INITIAL_WAVE_TABLE_SIZE * (61.74 / SAMPLE_RATE)
#define MUSIC_C2 INITIAL_WAVE_TABLE_SIZE * (65.41 / SAMPLE_RATE)
#define MUSIC_Db2 INITIAL_WAVE_TABLE_SIZE * (69.30 / SAMPLE_RATE)
#define MUSIC_D2 INITIAL_WAVE_TABLE_SIZE * (73.42 / SAMPLE_RATE)
#define MUSIC_Eb2 INITIAL_WAVE_TABLE_SIZE * (77.78 / SAMPLE_RATE)
#define MUSIC_E2 INITIAL_WAVE_TABLE_SIZE * (82.41 / SAMPLE_RATE)
#define MUSIC_F2 INITIAL_WAVE_TABLE_SIZE * (87.31 / SAMPLE_RATE)
#define MUSIC_Gb2 INITIAL_WAVE_TABLE_SIZE * (92.50 / SAMPLE_RATE)
#define MUSIC_G2 INITIAL_WAVE_TABLE_SIZE * (98.00 / SAMPLE_RATE)
#define MUSIC_Ab2 INITIAL_WAVE_TABLE_SIZE * (103.83 / SAMPLE_RATE)
#define MUSIC_A2 INITIAL_WAVE_TABLE_SIZE * (110.00 / SAMPLE_RATE)
#define MUSIC_Bb2 INITIAL_WAVE_TABLE_SIZE * (116.54 / SAMPLE_RATE)
#define MUSIC_B2 INITIAL_WAVE_TABLE_SIZE * (123.47 / SAMPLE_RATE)
#define MUSIC_C3 INITIAL_WAVE_TABLE_SIZE * (130.81 / SAMPLE_RATE)
#define MUSIC_Db3 INITIAL_WAVE_TABLE_SIZE * (138.59 / SAMPLE_RATE)
#define MUSIC_D3 INITIAL_WAVE_TABLE_SIZE * (146.83 / SAMPLE_RATE)
#define MUSIC_Eb3 INITIAL_WAVE_TABLE_SIZE * (155.56 / SAMPLE_RATE)
#define MUSIC_E3 INITIAL_WAVE_TABLE_SIZE * (164.81 / SAMPLE_RATE)
#define MUSIC_F3 INITIAL_WAVE_TABLE_SIZE * (174.61 / SAMPLE_RATE)
#define MUSIC_Gb3 INITIAL_WAVE_TABLE_SIZE * (185.00 / SAMPLE_RATE)
#define MUSIC_G3 INITIAL_WAVE_TABLE_SIZE * (196.00 / SAMPLE_RATE)
#define MUSIC_Ab3 INITIAL_WAVE_TABLE_SIZE * (207.65 / SAMPLE_RATE)
#define MUSIC_A3 INITIAL_WAVE_TABLE_SIZE * (220.00 / SAMPLE_RATE)
#define MUSIC_Bb3 INITIAL_WAVE_TABLE_SIZE * (233.08 / SAMPLE_RATE)
#define MUSIC_B3 INITIAL_WAVE_TABLE_SIZE * (246.94 / SAMPLE_RATE)
#define MUSIC_C4 INITIAL_WAVE_TABLE_SIZE * (261.63 / SAMPLE_RATE)
#define MUSIC_Db4 INITIAL_WAVE_TABLE_SIZE * (277.18 / SAMPLE_RATE)
#define MUSIC_D4 INITIAL_WAVE_TABLE_SIZE * (293.66 / SAMPLE_RATE)
#define MUSIC_Eb4 INITIAL_WAVE_TABLE_SIZE * (311.13 / SAMPLE_RATE)
#define MUSIC_E4 INITIAL_WAVE_TABLE_SIZE * (329.63 / SAMPLE_RATE)
#define MUSIC_F4 INITIAL_WAVE_TABLE_SIZE * (349.23 / SAMPLE_RATE)
#define MUSIC_Gb4 INITIAL_WAVE_TABLE_SIZE * (369.99 / SAMPLE_RATE)
#define MUSIC_G4 INITIAL_WAVE_TABLE_SIZE * (392.00 / SAMPLE_RATE)
#define MUSIC_Ab4 INITIAL_WAVE_TABLE_SIZE * (415.30 / SAMPLE_RATE)
#define MUSIC_A4 INITIAL_WAVE_TABLE_SIZE * (440.00 / SAMPLE_RATE)
#define MUSIC_Bb4 INITIAL_WAVE_TABLE_SIZE * (466.16 / SAMPLE_RATE)
#define MUSIC_B4 INITIAL_WAVE_TABLE_SIZE * (493.88 / SAMPLE_RATE)
#define MUSIC_C5 INITIAL_WAVE_TABLE_SIZE * (523.25 / SAMPLE_RATE)
#define MUSIC_Db5 INITIAL_WAVE_TABLE_SIZE * (554.37 / SAMPLE_RATE)
#define MUSIC_D5 INITIAL_WAVE_TABLE_SIZE * (587.33 / SAMPLE_RATE)
#define MUSIC_Eb5 INITIAL_WAVE_TABLE_SIZE * (622.25 / SAMPLE_RATE)
#define MUSIC_E5 INITIAL_WAVE_TABLE_SIZE * (659.25 / SAMPLE_RATE)
#define MUSIC_F5 INITIAL_WAVE_TABLE_SIZE * (698.46 / SAMPLE_RATE)
#define MUSIC_Gb5 INITIAL_WAVE_TABLE_SIZE * (739.99 / SAMPLE_RATE)
#define MUSIC_G5 INITIAL_WAVE_TABLE_SIZE * (783.99 / SAMPLE_RATE)
#define MUSIC_Ab5 INITIAL_WAVE_TABLE_SIZE * (830.61 / SAMPLE_RATE)
#define MUSIC_A5 INITIAL_WAVE_TABLE_SIZE * (880.00 / SAMPLE_RATE)
#define MUSIC_Bb5 INITIAL_WAVE_TABLE_SIZE * (932.33 / SAMPLE_RATE)
#define MUSIC_B5 INITIAL_WAVE_TABLE_SIZE * (987.77 / SAMPLE_RATE)
#define MUSIC_C6 INITIAL_WAVE_TABLE_SIZE * (1046.50 / SAMPLE_RATE)
#define MUSIC_Db6 INITIAL_WAVE_TABLE_SIZE * (1108.73 / SAMPLE_RATE)
#define MUSIC_D6 INITIAL_WAVE_TABLE_SIZE * (1174.66 / SAMPLE_RATE)
#define MUSIC_Eb6 INITIAL_WAVE_TABLE_SIZE * (1244.51 / SAMPLE_RATE)
#define MUSIC_E6 INITIAL_WAVE_TABLE_SIZE * (1318.51 / SAMPLE_RATE)
#define MUSIC_F6 INITIAL_WAVE_TABLE_SIZE * (1396.91 / SAMPLE_RATE)
#define MUSIC_Gb6 INITIAL_WAVE_TABLE_SIZE * (1479.98 / SAMPLE_RATE)
#define MUSIC_G6 INITIAL_WAVE_TABLE_SIZE * (1567.98 / SAMPLE_RATE)
#define MUSIC_Ab6 INITIAL_WAVE_TABLE_SIZE * (1661.22 / SAMPLE_RATE)
#define MUSIC_A6 INITIAL_WAVE_TABLE_SIZE * (1760.00 / SAMPLE_RATE)
#define MUSIC_Bb6 INITIAL_WAVE_TABLE_SIZE * (1864.66 / SAMPLE_RATE)
#define MUSIC_B6 INITIAL_WAVE_TABLE_SIZE * (1975.53 / SAMPLE_RATE)
#define MUSIC_C7 INITIAL_WAVE_TABLE_SIZE * (2093.00 / SAMPLE_RATE)
#define MUSIC_Db7 INITIAL_WAVE_TABLE_SIZE * (2217.46 / SAMPLE_RATE)
#define MUSIC_D7 INITIAL_WAVE_TABLE_SIZE * (2349.32 / SAMPLE_RATE)
#define MUSIC_Eb7 INITIAL_WAVE_TABLE_SIZE * (2489.02 / SAMPLE_RATE)
#define MUSIC_E7 INITIAL_WAVE_TABLE_SIZE * (2637.02 / SAMPLE_RATE)
#define MUSIC_F7 INITIAL_WAVE_TABLE_SIZE * (2793.83 / SAMPLE_RATE)
#define MUSIC_Gb7 INITIAL_WAVE_TABLE_SIZE * (2959.96 / SAMPLE_RATE)
#define MUSIC_G7 INITIAL_WAVE_TABLE_SIZE * (3135.96 / SAMPLE_RATE)
#define MUSIC_Ab7 INITIAL_WAVE_TABLE_SIZE * (3322.44 / SAMPLE_RATE)
#define MUSIC_A7 INITIAL_WAVE_TABLE_SIZE * (3520.00 / SAMPLE_RATE)
#define MUSIC_Bb7 INITIAL_WAVE_TABLE_SIZE * (3729.31 / SAMPLE_RATE)
#define MUSIC_B7 INITIAL_WAVE_TABLE_SIZE * (3951.07 / SAMPLE_RATE)
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

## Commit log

2019-01-31 Added files for tutorial 1
    [BITBA555_tutorial1.fzz]
2019-02-05 Added pictures of schematic and breadboard layout
2019-02-19 Tutorial 2 files added, and restructuring of file structure
    [BITBA555_tutorial2.fzz]
2019-03-12 Added tutorial 3 files
    [BITBA555_tutorial2.fzz, BITBA555_tutorial3.fzz]
2019-04-11 Adding Tutorial 4 files
    [BITBA555_tutorial2.fzz, BITBA555_tutorial3.fzz]
2019-04-11 Finished adding files for tutorial 4
    [BITBA555_tutorial4.fzz]
2019-04-16 adding tentative tutorial 5 files
    [BITBA555_tutorial4.fzz, BITBA555_tutorial5.fzz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]
2019-05-08 fixing board files
    [BITBA555_tutorial5.fzz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]
2019-05-29 adding final files for tutorial 5
    [BITBA555_tutorial5.fzz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]
2019-08-01 Adding stl files for 3D printing and collecting completed files
    [BITBA555_tutorial5.fzz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]
